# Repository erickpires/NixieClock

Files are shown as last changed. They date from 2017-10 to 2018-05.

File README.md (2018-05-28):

# The Project

This is a clock that uses Nixie Tubes as display. The idea is not new and there are hundreds of others Nixie based clock on the internet.
I got inspired to build the clock after watching a video from [Techmoan](https://www.youtube.com/channel/UC5I2hjZYiW9gZPVkvzM8_Cw).

## The Nixies

The Nixie Tubes were bought from eBay. They are IN-14 tubes desoldered from unused replacement board for old equipment (so the seller told me).

To drive the Nixies, six K155ID1 (the Russian version of the 74141) were also bought from eBay (which turned out to be a bad idea since those chips are very old, not reliable and consume too much power).

The Nixies are powered with 170V and half of their nominal amperage (this should extend their lifetime).

## The Boards

The clock is divided in three boards: a High-Voltage Power Supply for the Nixie Tubes, a Logic Board and a board to hold the Nixies.

* The Power Supply was built on a prototyping PCB based on two designs found online. More information can be found on the Power Supply directory of this repository.

* The Logic Board contains an Atmel Atmega 328p microcontroller which implements the clock in software. This board also contains some passive components and connectors. The schematic and the PCB design was done using kicad and can be found under the kicad/LowerBoard directory. The board itself was homemade using the toner transfer technique (more information can be found online) and etched using ferric chloride.

* The third board holds the Nixie Tubes as well as the six driver ICs and three 74HC573 8-bit transparent latches. This board also functions as the upper face of the clock and the ICs were put in this board because I thought it would be more aesthetically pleasing. The PCB design can be found under the kicad/Clock directory. This board was made using the same technique as the Logic Board.

## The Code

The code runs on an Atmega 328p with an Arduino bootloader. The code doesn't use any of the Arduino library functions, accessing registers directly. The code should work fine without the Arduino environment and using the Atmel Studio. The Arduino environment is used only to provide a n easy way of uploading the code into the microcontroller.

The clock is implemented in software, as already mentioned. The code also handles debouncing of the input buttons and rotary encoder.

Every whole minute the clock plays an animation in which all digits of all Nixie Tubes are lit twice. The primary reason for the animation is to avoid [Cathode Poisoning](http://www.tube-tester.com/sites/nixie/different/cathode%20poisoning/cathode-poisoning.htm) since must of the digits don't change too often (and some digits aren't even lit) but also because it looks cool.

From midnight to 6AM the display is shutdown. This should save some lifetime out of the Nixies. Upon interaction with any button (or rotary encoder) while the display is off, it turns on for 5 seconds.

An alarm clock functionality is planned, but not yet implemented.

## Final Result

Here are two photos of the clock working.

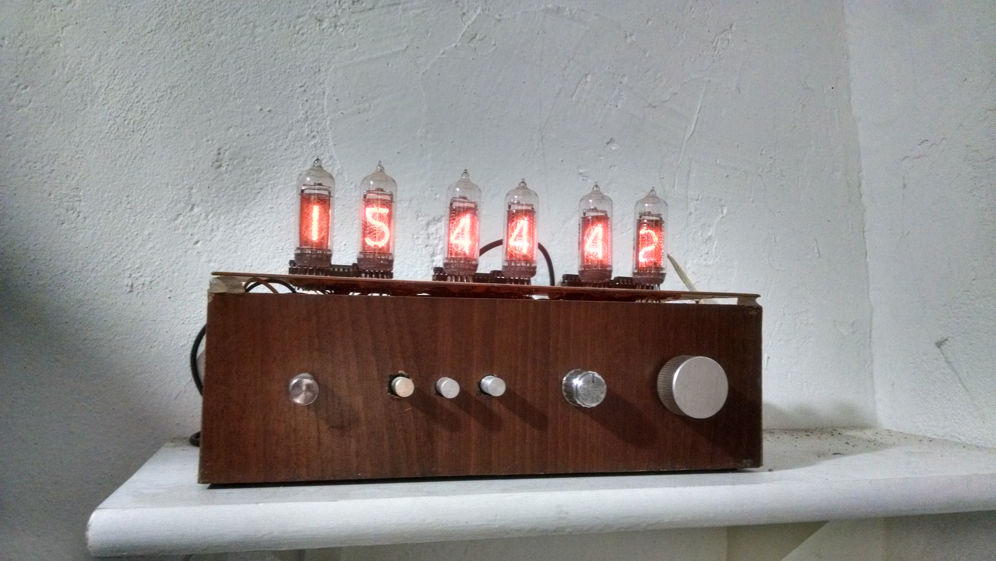
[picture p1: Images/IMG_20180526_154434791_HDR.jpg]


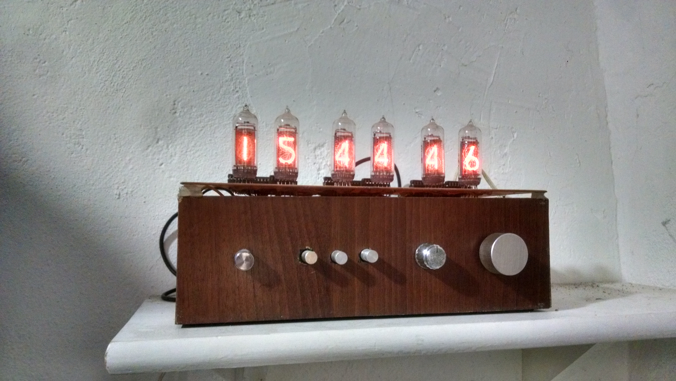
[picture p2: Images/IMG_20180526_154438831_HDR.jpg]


and a video:

Video (https://youtu.be/pQ4-Zf7qyXU)

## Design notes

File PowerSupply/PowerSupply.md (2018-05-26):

# Power Supply

The Power Supply is based in this two designs:

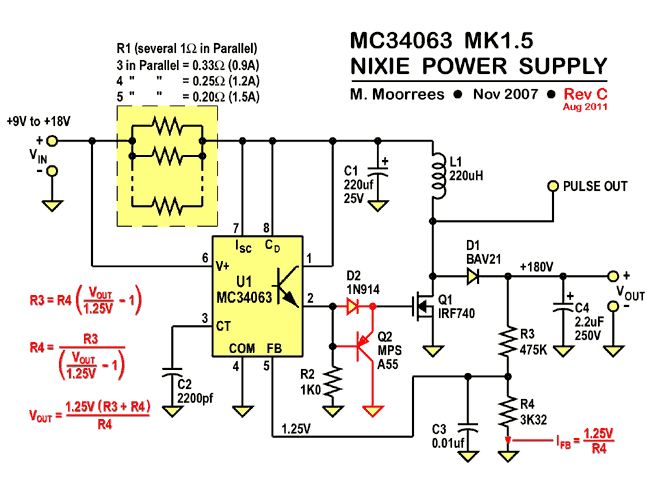
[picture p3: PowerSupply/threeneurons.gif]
ThreeNeurons


and

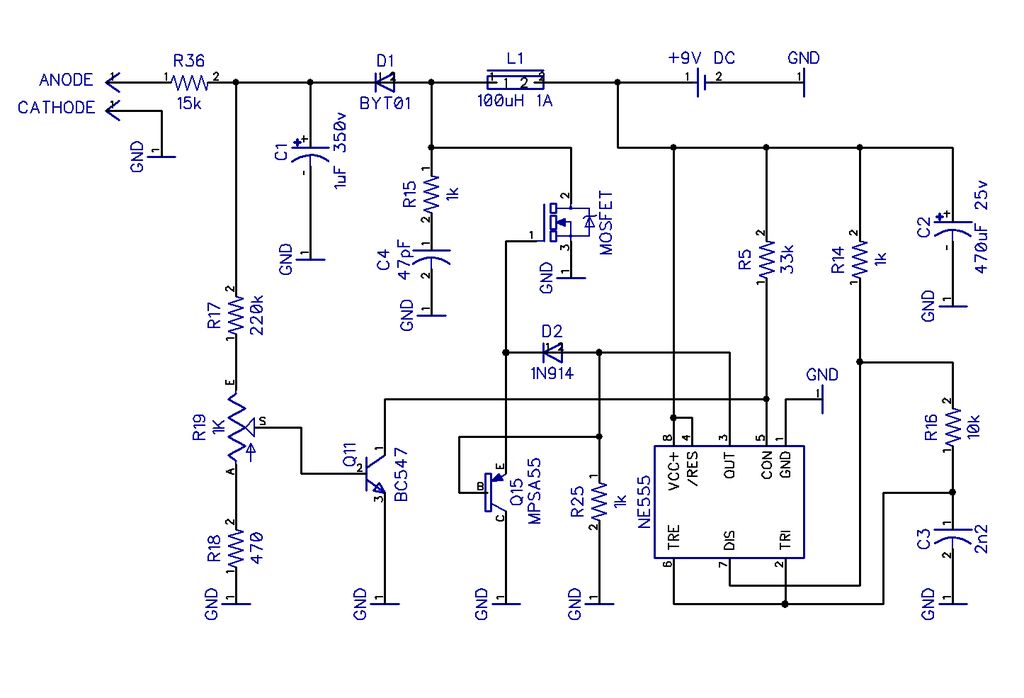
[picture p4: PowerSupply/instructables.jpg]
Instructables


Found in theses two links: [threeneurons](https://threeneurons.wordpress.com/nixie-power-supply/) and [Instructables](http://www.instructables.com/id/High-Voltage-Power-Supply-for-Nixie-and-Valve-Tube/)

Unfortunately I don't have a schematic from the actual Power Supply.

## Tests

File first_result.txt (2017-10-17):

First correction
23:15:31 -> 0:57:0

10:07:01 -> 11:48:00
39090 segundos -> 39060

Second correction : first attempt
10:25:33(~32) -> 0:1:0
Failed miserably

Second correction : second attempt
22:52:24 -> 0:1:0

13:49:21 -> 14:58:0
53817 segundos -> 53820

Third correction
14:04:38 -> 0:1:0

10:12:39 -> 20:9:0
72481 segundos -> 72480

Fourth correction
15:42:50 -> 0:6:0

10:51:58 -> 19:14:0

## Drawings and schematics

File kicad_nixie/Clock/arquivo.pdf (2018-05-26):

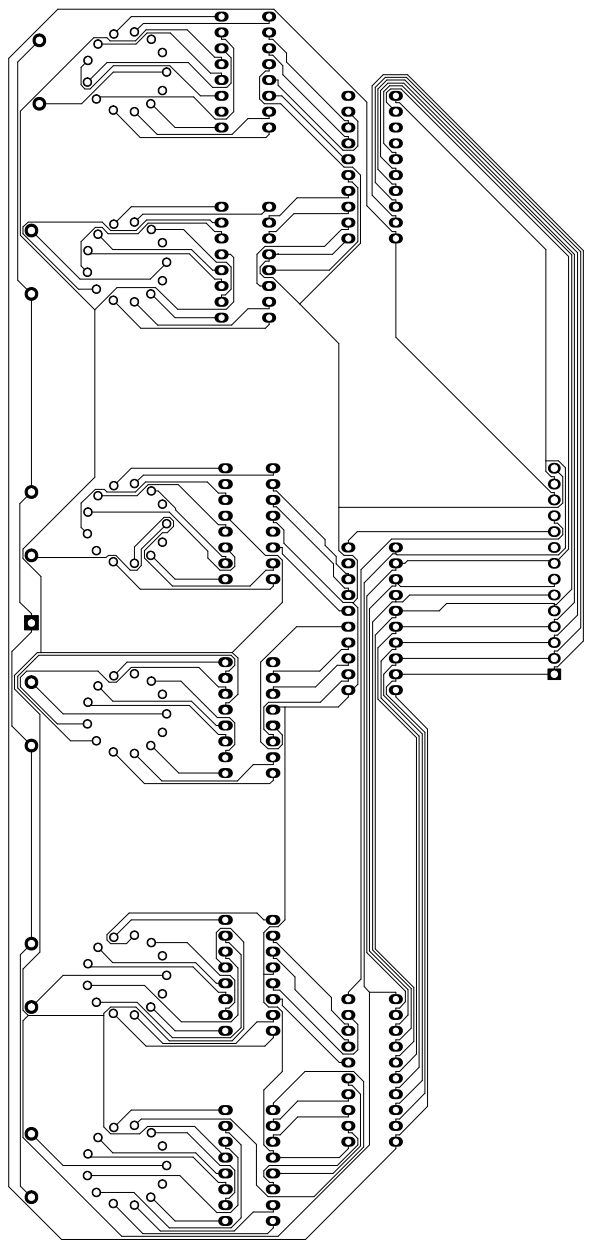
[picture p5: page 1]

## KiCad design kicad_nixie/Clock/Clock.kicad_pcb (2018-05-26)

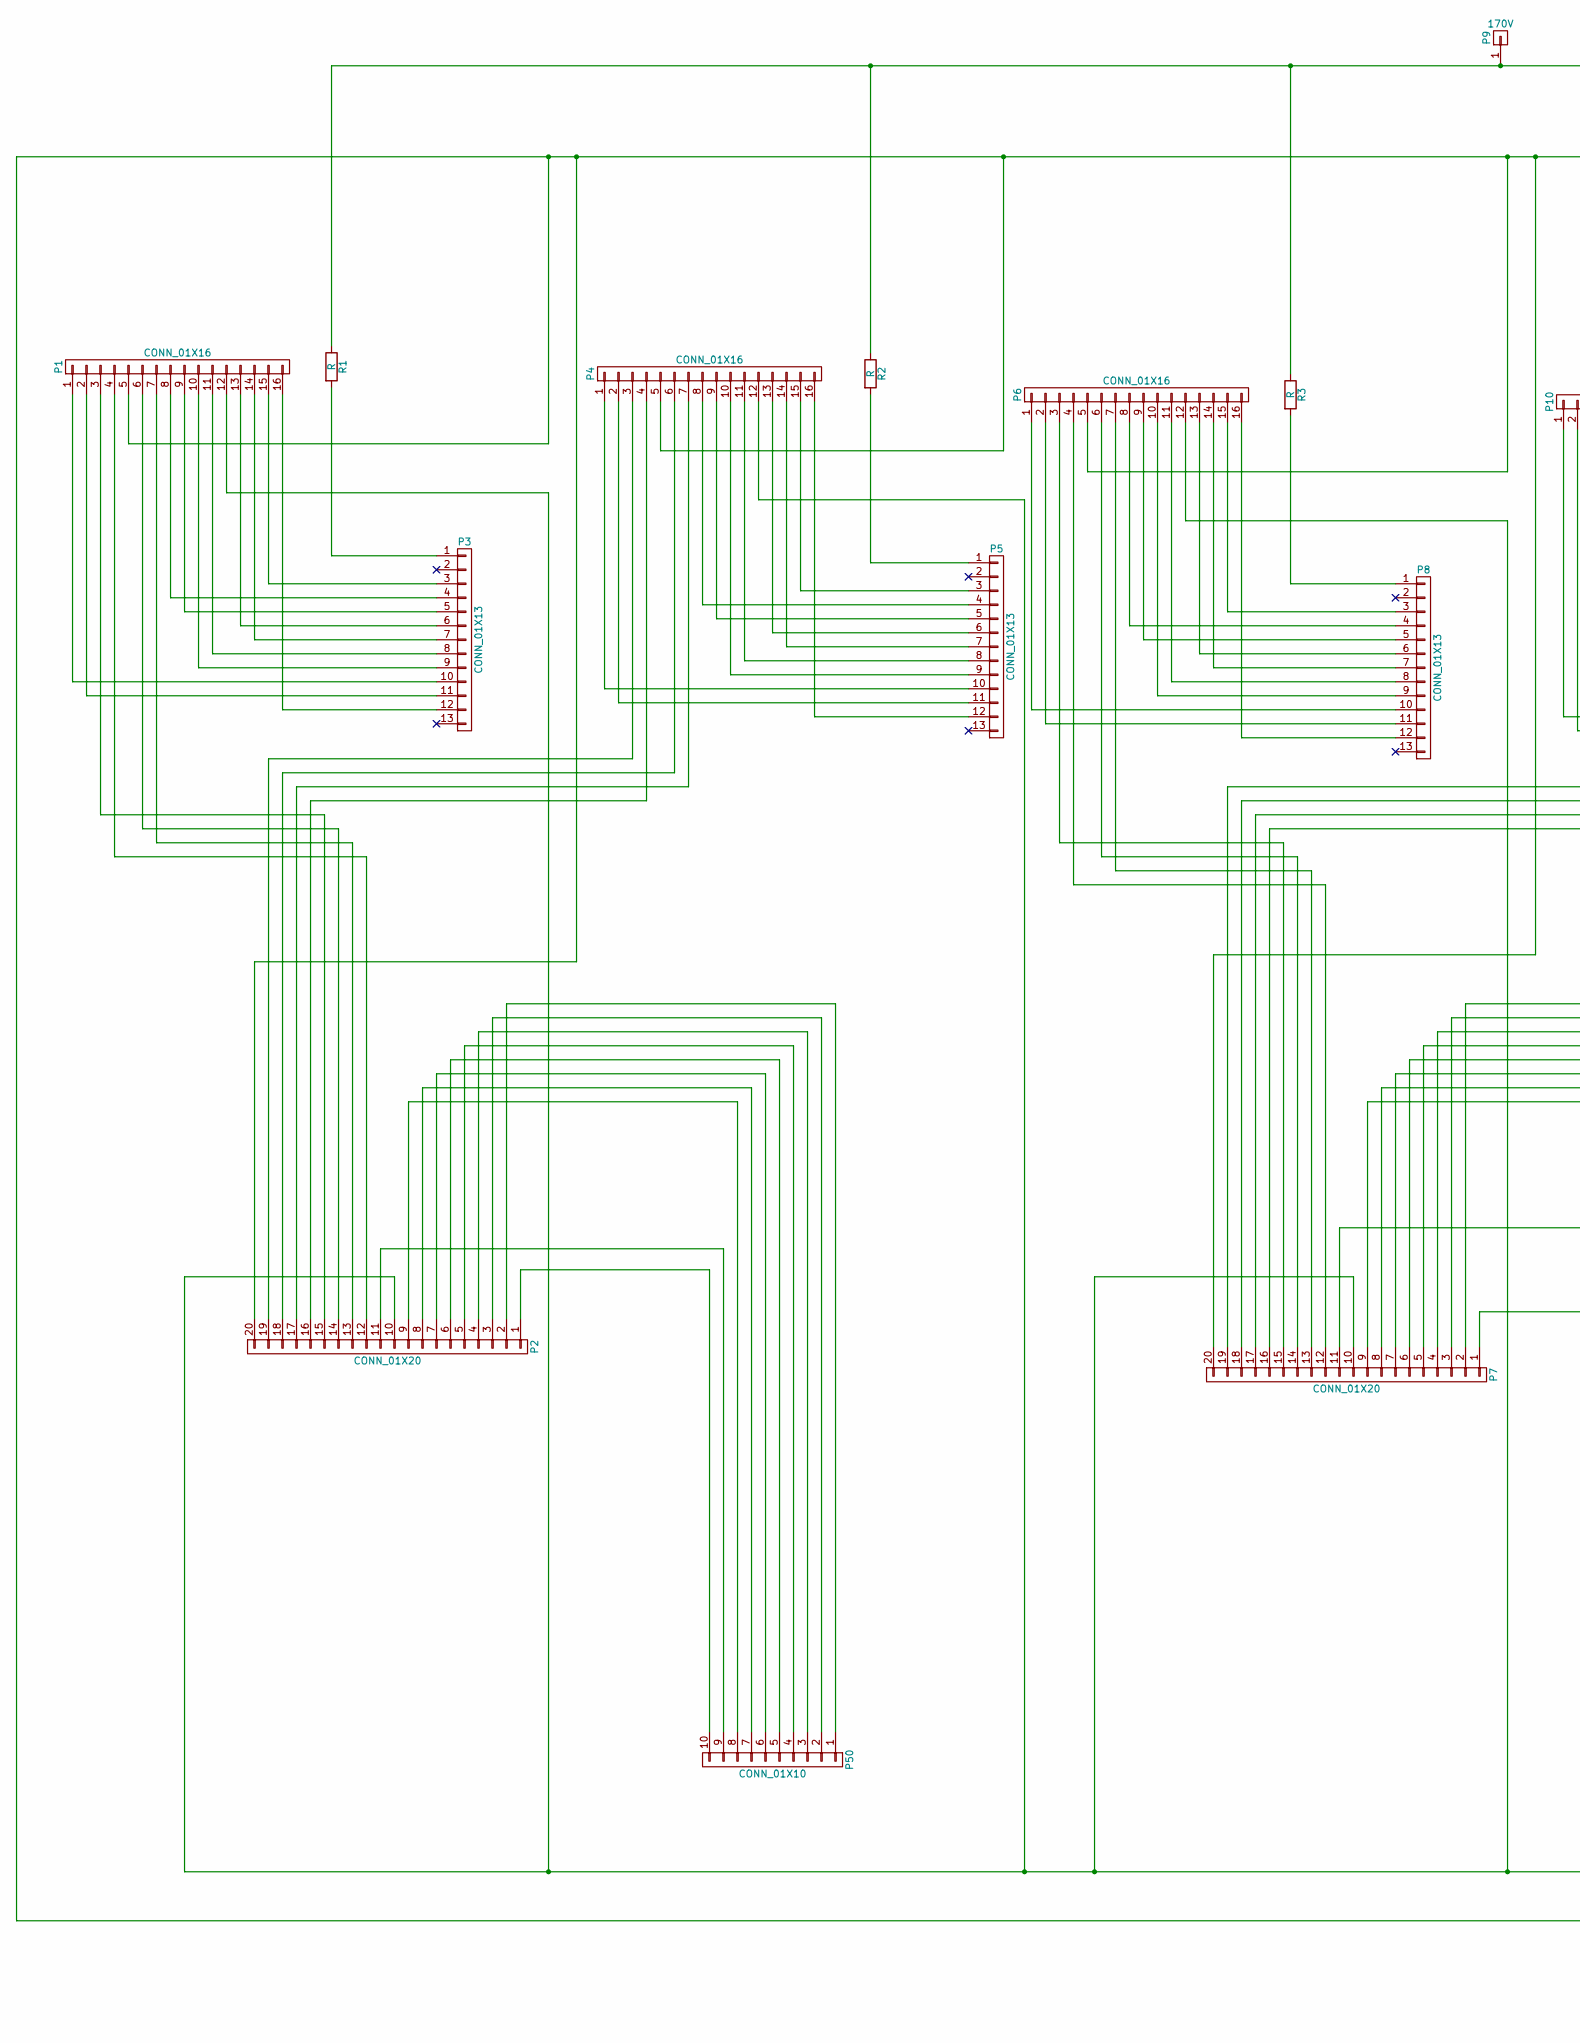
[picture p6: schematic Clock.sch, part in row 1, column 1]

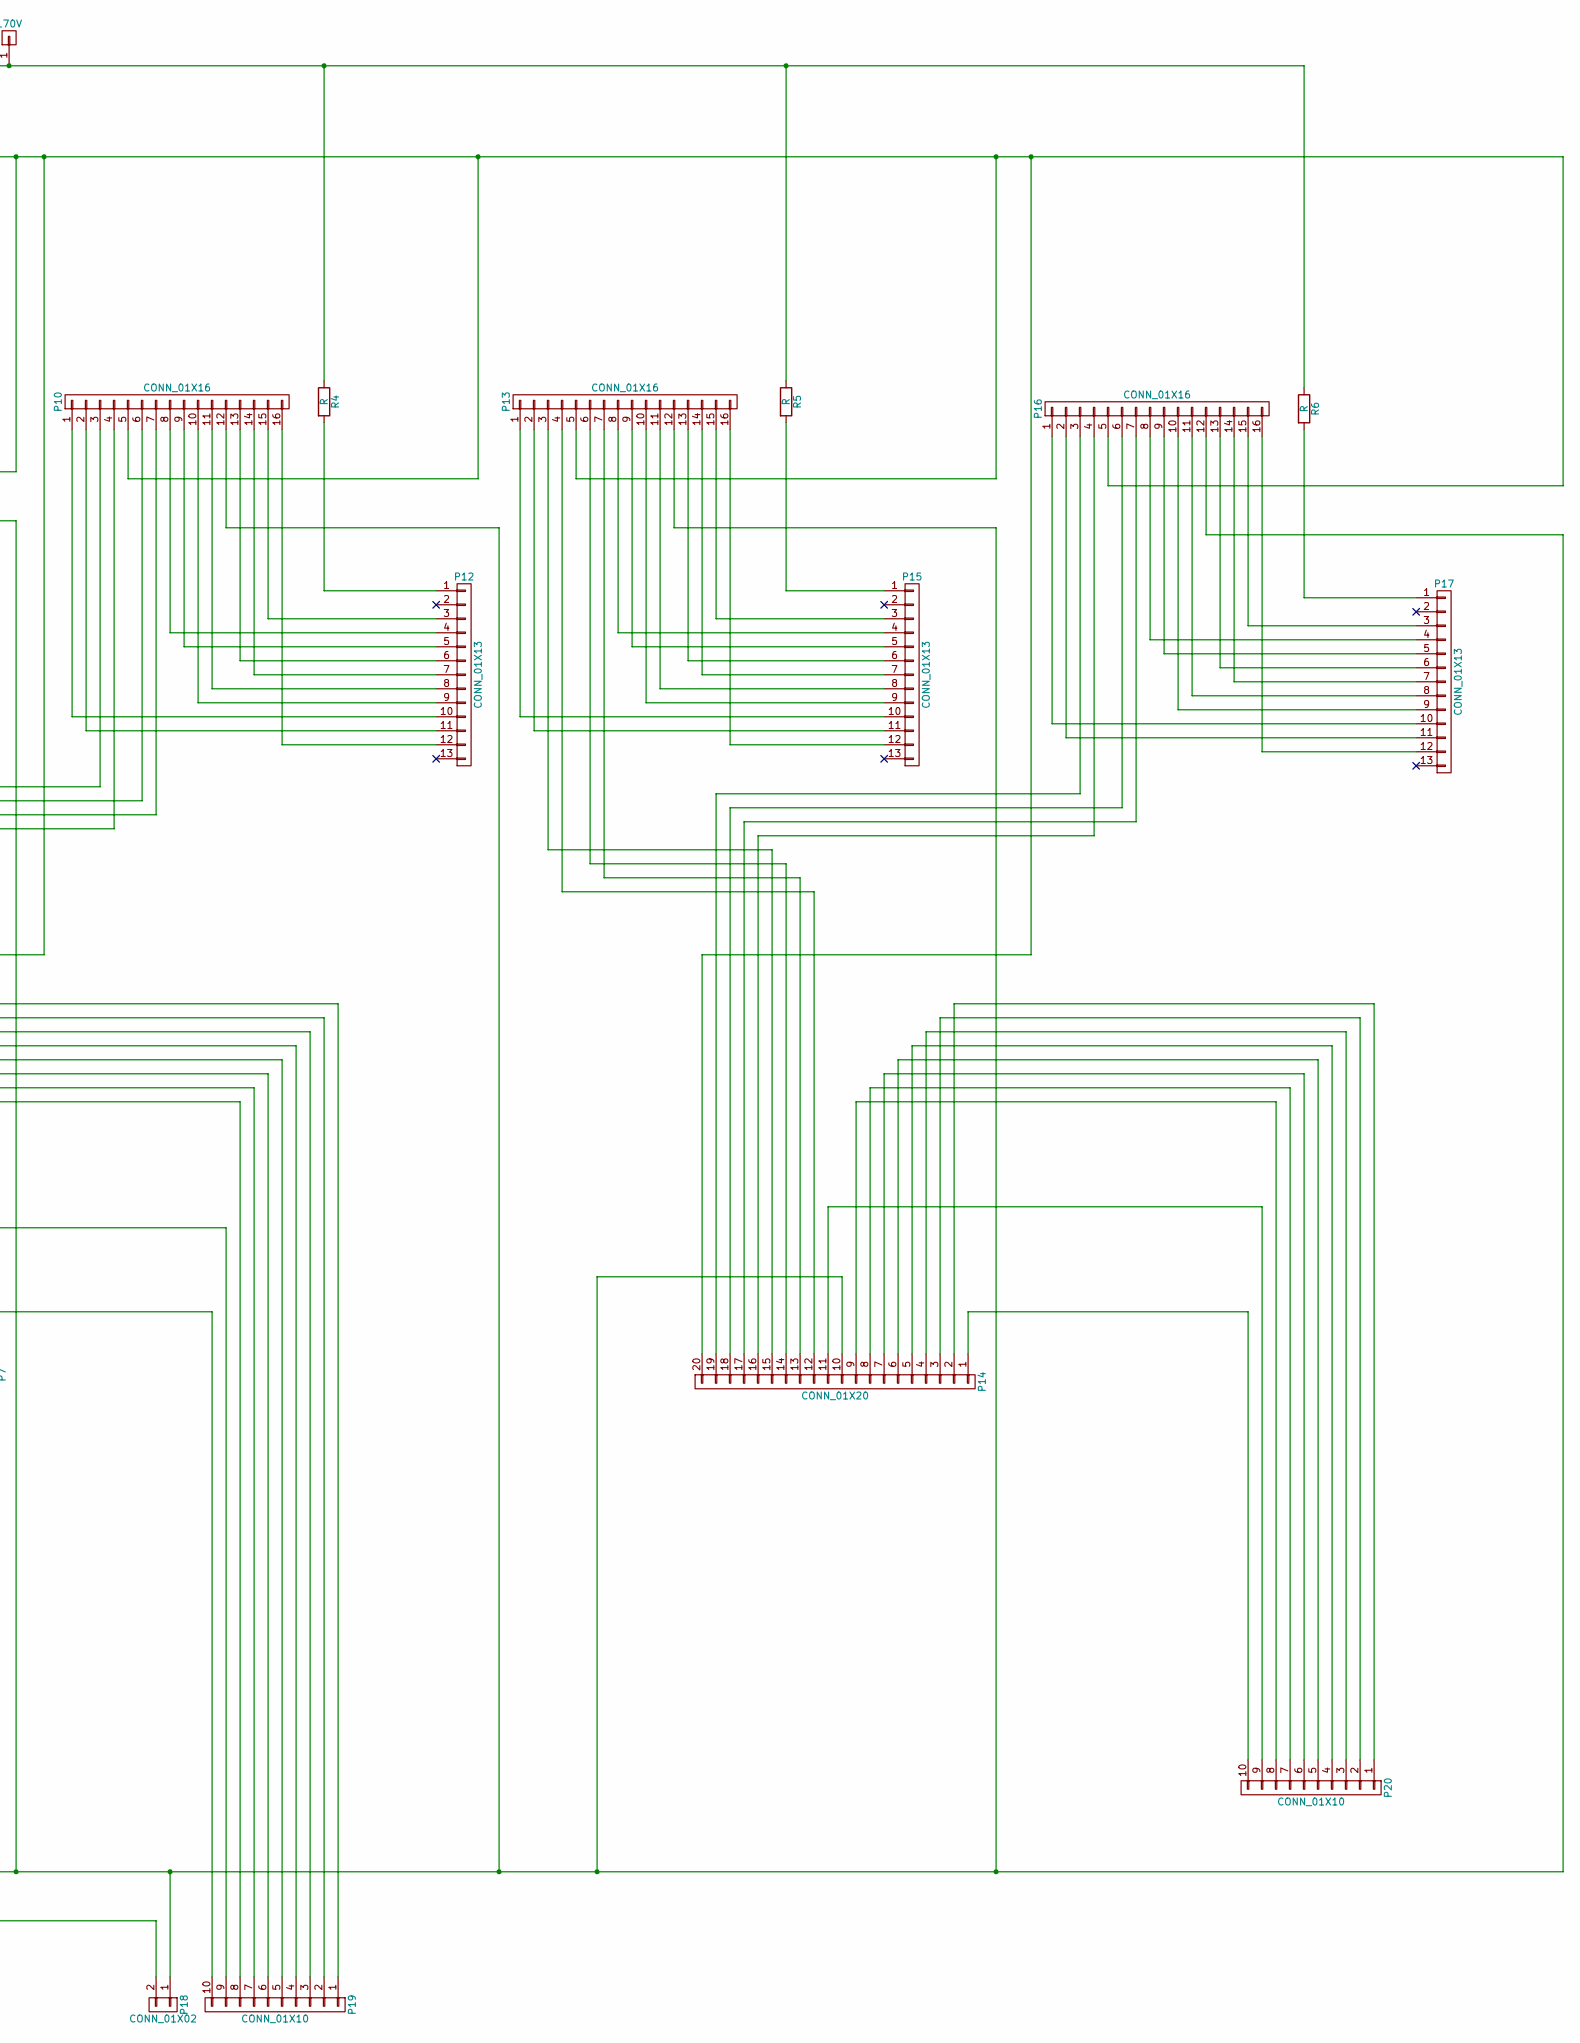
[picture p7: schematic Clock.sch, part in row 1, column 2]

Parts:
P1, P4, P6, P10, P13, P16: CONN_01X16; DIP-16_W7.62mm_LongPads
P2, P7, P14: CONN_01X20; DIP-20_W7.62mm_LongPads
P3, P5, P8, P12, P15, P17: CONN_01X13; IN-14-mod
P9: 170V; Pin_Header_Straight_1x01
P18: CONN_01X02; Pin_Header_Straight_1x02
P19, P20, P50: CONN_01X10; Pin_Header_Straight_1x10
R1, R2, R3, R4, R5, R6: R; Resistor_Horizontal_RM10mm

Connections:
unnamed: P1.1, P3.10
unnamed: P1.2, P3.11
unnamed: P1.3, P2.15
unnamed: P1.4, P2.12
unnamed: P1.5, P2.20, P4.5, P6.5, P7.20, P10.5, P13.5, P14.20, P16.5, P18.2
unnamed: P1.6, P2.14
unnamed: P1.7, P2.13
unnamed: P1.8, P3.4
unnamed: P1.9, P3.5
unnamed: P1.10, P3.9
unnamed: P1.11, P3.8
unnamed: P1.12, P2.10, P4.12, P6.12, P7.10, P10.12, P13.12, P14.10, P16.12, P18.1
unnamed: P1.13, P3.6
unnamed: P1.14, P3.7
unnamed: P1.15, P3.3
unnamed: P1.16, P3.12
unnamed: P2.1, P50.10
unnamed: P2.2, P50.1
unnamed: P2.3, P50.2
unnamed: P2.4, P50.3
unnamed: P2.5, P50.4
unnamed: P2.6, P50.5
unnamed: P2.7, P50.6
unnamed: P2.8, P50.7
unnamed: P2.9, P50.8
unnamed: P2.11, P50.9
unnamed: P2.16, P4.4
unnamed: P2.17, P4.7
unnamed: P2.18, P4.6
unnamed: P2.19, P4.3
unnamed: P3.1, R1.2
unnamed: P4.1, P5.10
unnamed: P4.2, P5.11
unnamed: P4.8, P5.4
unnamed: P4.9, P5.5
unnamed: P4.10, P5.9
unnamed: P4.11, P5.8
unnamed: P4.13, P5.6
unnamed: P4.14, P5.7
unnamed: P4.15, P5.3
unnamed: P4.16, P5.12
unnamed: P5.1, R2.2
unnamed: P6.1, P8.10
unnamed: P6.2, P8.11
unnamed: P6.3, P7.15
unnamed: P6.4, P7.12
unnamed: P6.6, P7.14
unnamed: P6.7, P7.13
unnamed: P6.8, P8.4
unnamed: P6.9, P8.5
unnamed: P6.10, P8.9
unnamed: P6.11, P8.8
unnamed: P6.13, P8.6
unnamed: P6.14, P8.7
unnamed: P6.15, P8.3
unnamed: P6.16, P8.12
unnamed: P8.1, R3.2
unnamed: P9.1, R1.1, R2.1, R3.1, R4.1, R5.1, R6.1
unnamed: P10.1, P12.10
unnamed: P10.2, P12.11
unnamed: P7.19, P10.3
unnamed: P7.16, P10.4
unnamed: P7.18, P10.6
unnamed: P7.17, P10.7
unnamed: P10.8, P12.4
unnamed: P10.9, P12.5
unnamed: P10.10, P12.9
unnamed: P10.11, P12.8
unnamed: P10.13, P12.6
unnamed: P10.14, P12.7
unnamed: P10.15, P12.3
unnamed: P10.16, P12.12
unnamed: P12.1, R4.2
unnamed: P13.1, P15.10
unnamed: P13.2, P15.11
unnamed: P13.3, P14.15
unnamed: P13.4, P14.12
unnamed: P13.6, P14.14
unnamed: P13.7, P14.13
unnamed: P13.8, P15.4
unnamed: P13.9, P15.5
unnamed: P13.10, P15.9
unnamed: P13.11, P15.8
unnamed: P13.13, P15.6
unnamed: P13.14, P15.7
unnamed: P13.15, P15.3
unnamed: P13.16, P15.12
unnamed: P14.1, P20.10
unnamed: P14.2, P20.1
unnamed: P14.3, P20.2
unnamed: P14.4, P20.3
unnamed: P14.5, P20.4
unnamed: P14.6, P20.5
unnamed: P14.7, P20.6
unnamed: P14.8, P20.7
unnamed: P14.9, P20.8
unnamed: P14.11, P20.9
unnamed: P14.16, P16.4
unnamed: P14.17, P16.7
unnamed: P14.18, P16.6
unnamed: P14.19, P16.3
unnamed: P15.1, R5.2
unnamed: P16.1, P17.10
unnamed: P16.2, P17.11
unnamed: P16.8, P17.4
unnamed: P16.9, P17.5
unnamed: P16.10, P17.9
unnamed: P16.11, P17.8
unnamed: P16.13, P17.6
unnamed: P16.14, P17.7
unnamed: P16.15, P17.3
unnamed: P16.16, P17.12
unnamed: P17.1, R6.2
unnamed: P7.2, P19.1
unnamed: P7.3, P19.2
unnamed: P7.4, P19.3
unnamed: P7.5, P19.4
unnamed: P7.6, P19.5
unnamed: P7.7, P19.6
unnamed: P7.8, P19.7
unnamed: P7.9, P19.8
unnamed: P7.11, P19.9
unnamed: P7.1, P19.10

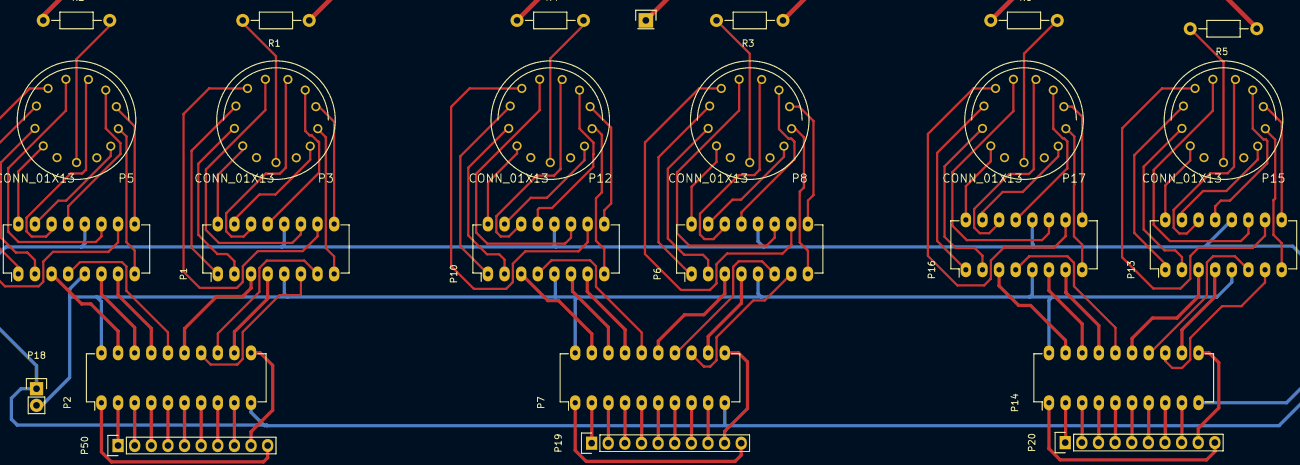
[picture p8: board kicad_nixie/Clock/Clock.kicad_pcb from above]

Board: 2 copper layers, 26 parts (0 on the bottom side), 123 nets.

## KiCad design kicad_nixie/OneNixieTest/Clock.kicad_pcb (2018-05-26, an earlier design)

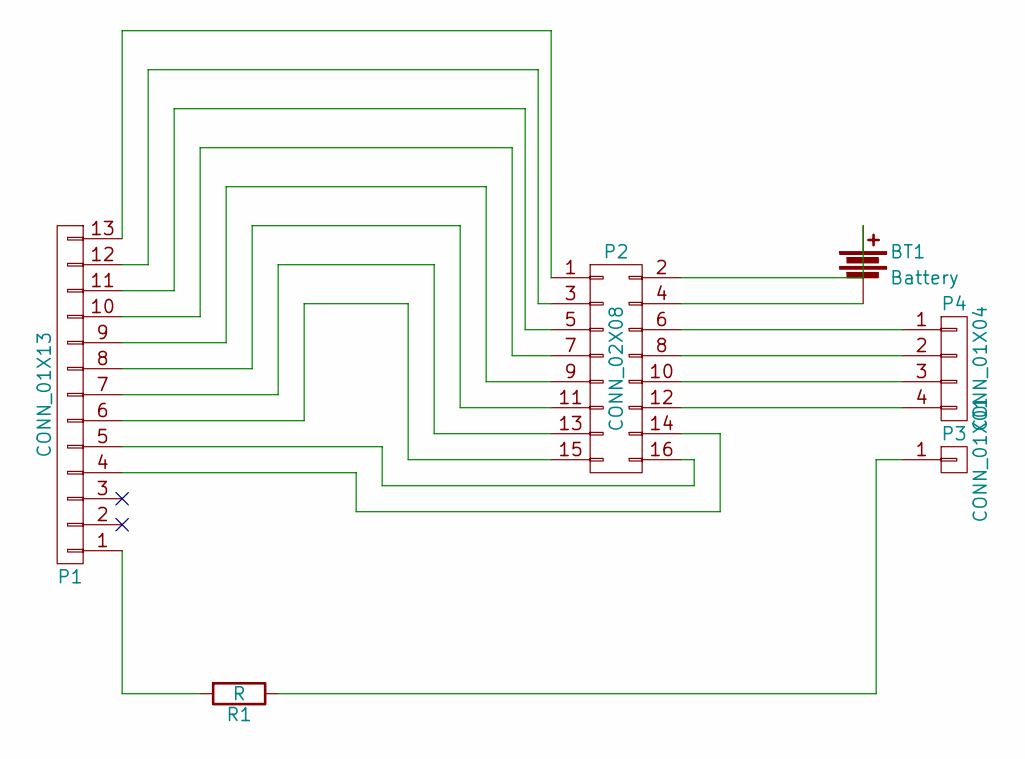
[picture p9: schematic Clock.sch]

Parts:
BT1: Battery; Pin_Header_Straight_1x02
P1: CONN_01X13; IN-14-mod
P2: CONN_02X08; DIP-16_W7.62mm_LongPads
P3: CONN_01X01; Pin_Header_Straight_1x01
P4: CONN_01X04; Pin_Header_Straight_1x04
R1: R; Resistor_Horizontal_RM10mm

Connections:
unnamed: BT1.1, P2.2
unnamed: BT1.2, P2.4
unnamed: P1.1, R1.2
unnamed: P1.4, P2.14
unnamed: P1.5, P2.16
unnamed: P1.6, P2.15
unnamed: P1.7, P2.13
unnamed: P1.8, P2.11
unnamed: P1.9, P2.9
unnamed: P1.10, P2.7
unnamed: P1.11, P2.5
unnamed: P1.12, P2.3
unnamed: P1.13, P2.1
unnamed: P2.6, P4.1
unnamed: P2.8, P4.2
unnamed: P2.10, P4.3
unnamed: P2.12, P4.4
unnamed: P3.1, R1.1

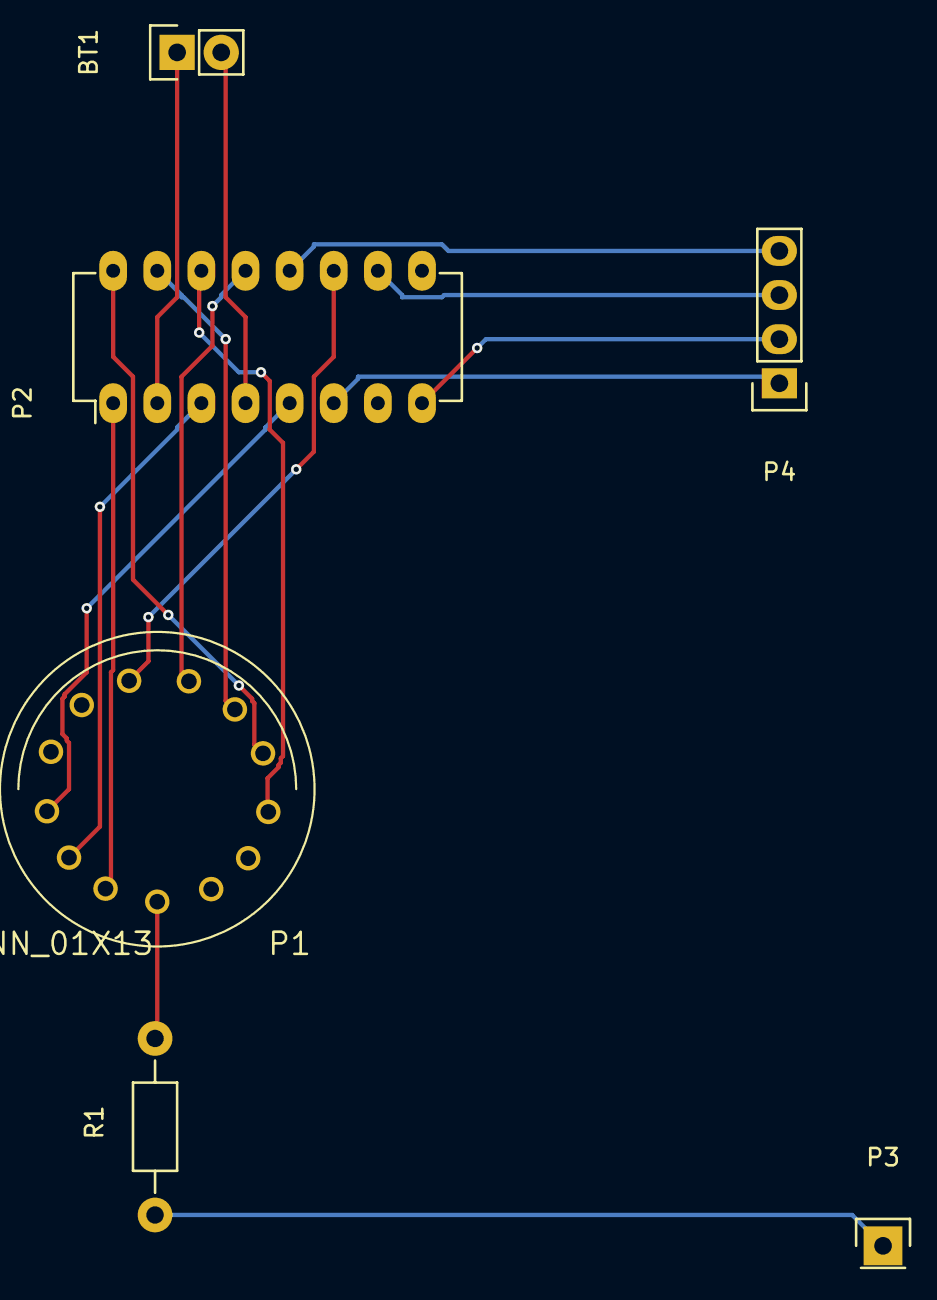
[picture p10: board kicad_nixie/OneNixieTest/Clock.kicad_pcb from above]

Board: 2 copper layers, 6 parts (0 on the bottom side), 18 nets.

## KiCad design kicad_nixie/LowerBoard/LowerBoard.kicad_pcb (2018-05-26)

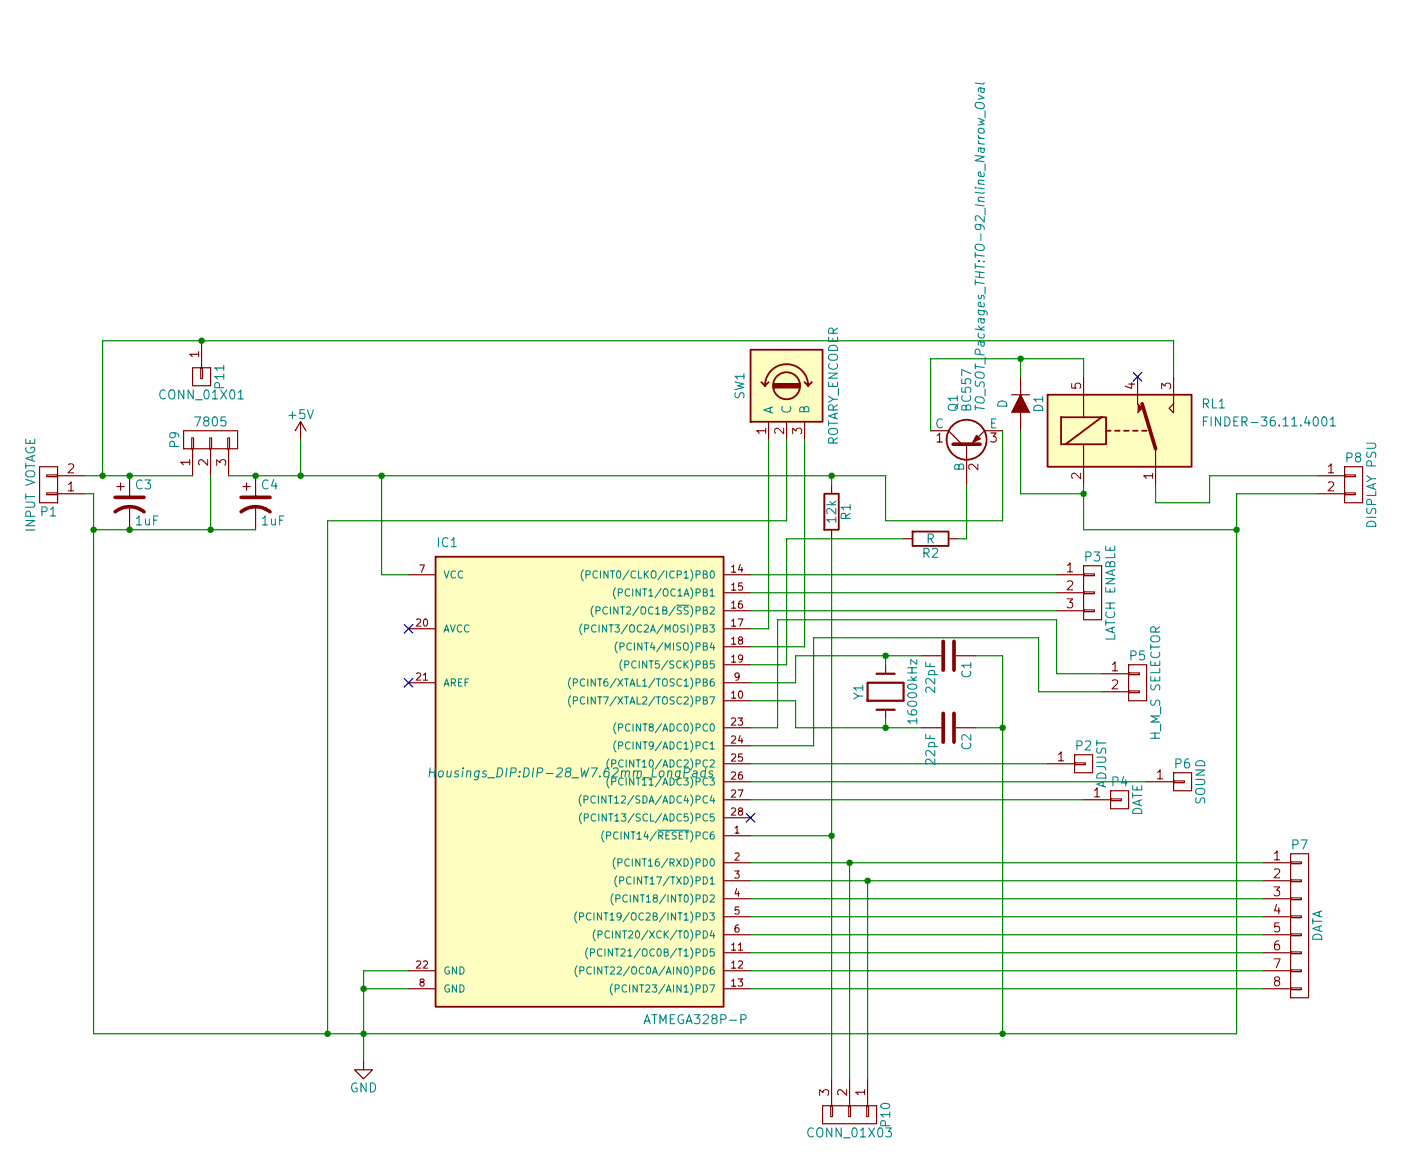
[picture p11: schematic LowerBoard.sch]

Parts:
C1, C2: 22pF; C_Disc_D3_P2.5
C3, C4: 1uF; C_Radial_D5_L11_P2.5
D1: D; Diode_DO-35_SOD27_Horizontal_RM10
IC1: ATMEGA328P-P; DIP-28_W7.62mm_LongPads
P1: INPUT VOTAGE; Pin_Header_Straight_1x02
P2: ADJUST; Pin_Header_Straight_1x01
P3: LATCH ENABLE; Pin_Header_Straight_1x03
P4: DATE; Pin_Header_Straight_1x01
P5: H_M_S SELECTOR; Pin_Header_Straight_1x02
P6: SOUND; Pin_Header_Straight_1x01
P7: DATA; Pin_Header_Straight_1x08
P8: DISPLAY PSU; Pin_Header_Straight_1x02
P9: 7805; TO-220
P10: CONN_01X03; Pin_Header_Straight_1x03
P11: CONN_01X01; Pin_Header_Straight_1x01
Q1: BC557; TO-92_Inline_Narrow_Oval
R1: 12k; Resistor_Horizontal_RM7mm
R2: R; Resistor_Horizontal_RM7mm
RL1: FINDER-36.11.4001; Relay_SANYOU_SRD_Series_Form_C
SW1: ROTARY_ENCODER; Pin_Header_Straight_1x03
Y1: 16000kHz; Crystal_HC50-U_Vertical

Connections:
+5V: C4.1, IC1.7 (VCC), P9.3, Q1.3 (E), R1.1
GND: C1.1, C2.1, C3.2, C4.2, D1.2 (A), IC1.8 (GND), IC1.22 (GND), P1.1, P8.2, P9.2, RL1.2, SW1.2 (C)
unnamed: C1.2, IC1.9 ((PCINT6/XTAL1/TOSC1)PB6), Y1.2
unnamed: C2.2, IC1.10 ((PCINT7/XTAL2/TOSC2)PB7), Y1.1
unnamed: C3.1, P1.2, P9.1, P11.1, RL1.3
unnamed: D1.1 (K), Q1.1 (C), RL1.5
unnamed: IC1.1 ((PCINT14/~RESET~)PC6), P10.3, R1.2
unnamed: IC1.2 ((PCINT16/RXD)PD0), P7.1, P10.2
unnamed: IC1.3 ((PCINT17/TXD)PD1), P7.2, P10.1
unnamed: IC1.4 ((PCINT18/INT0)PD2), P7.3
unnamed: IC1.5 ((PCINT19/OC2B/INT1)PD3), P7.4
unnamed: IC1.6 ((PCINT20/XCK/T0)PD4), P7.5
unnamed: IC1.11 ((PCINT21/OC0B/T1)PD5), P7.6
unnamed: IC1.12 ((PCINT22/OC0A/AIN0)PD6), P7.7
unnamed: IC1.13 ((PCINT23/AIN1)PD7), P7.8
unnamed: IC1.14 ((PCINT0/CLKO/ICP1)PB0), P3.1
unnamed: IC1.15 ((PCINT1/OC1A)PB1), P3.2
unnamed: IC1.16 ((PCINT2/OC1B/~SS~)PB2), P3.3
unnamed: IC1.17 ((PCINT3/OC2A/MOSI)PB3), SW1.1 (A)
unnamed: IC1.18 ((PCINT4/MISO)PB4), SW1.3 (B)
unnamed: IC1.19 ((PCINT5/SCK)PB5), R2.2
unnamed: IC1.23 ((PCINT8/ADC0)PC0), P5.1
unnamed: IC1.24 ((PCINT9/ADC1)PC1), P5.2
unnamed: IC1.25 ((PCINT10/ADC2)PC2), P2.1
unnamed: IC1.26 ((PCINT11/ADC3)PC3), P6.1
unnamed: IC1.27 ((PCINT12/SDA/ADC4)PC4), P4.1
unnamed: P8.1, RL1.1
unnamed: Q1.2 (B), R2.1

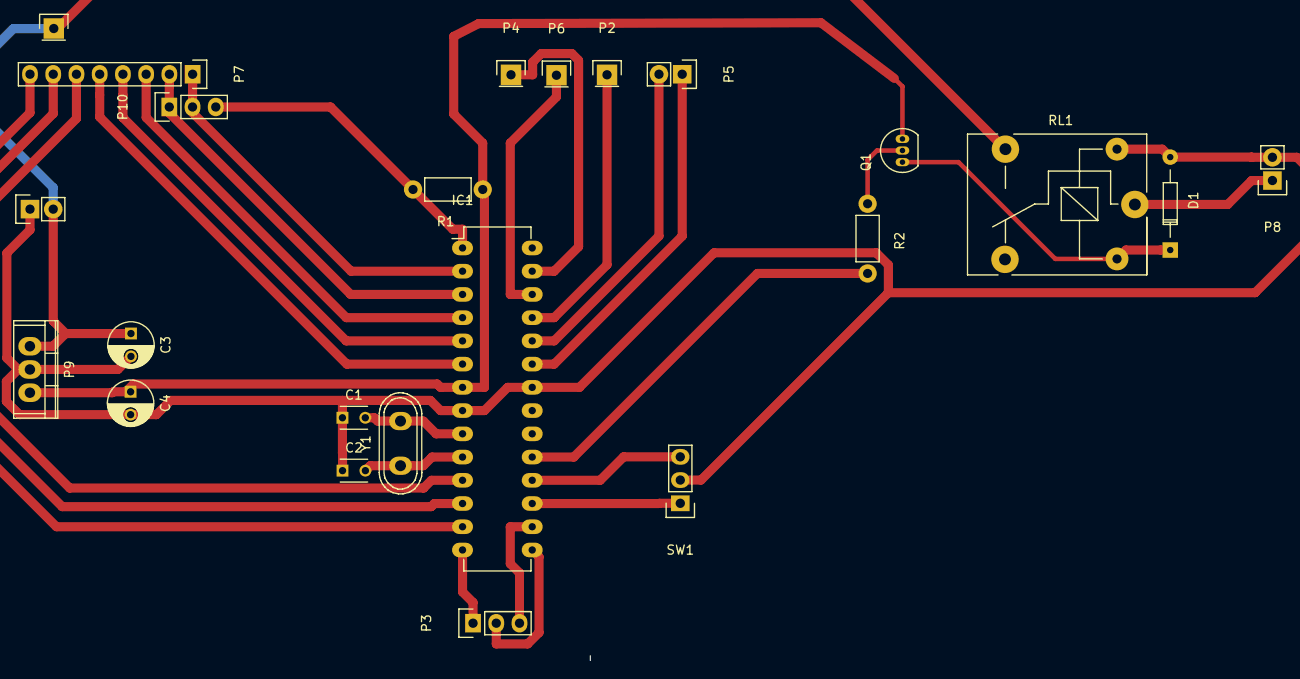
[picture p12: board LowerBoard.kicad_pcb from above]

Board: 2 copper layers, 23 parts (0 on the bottom side), 28 nets.

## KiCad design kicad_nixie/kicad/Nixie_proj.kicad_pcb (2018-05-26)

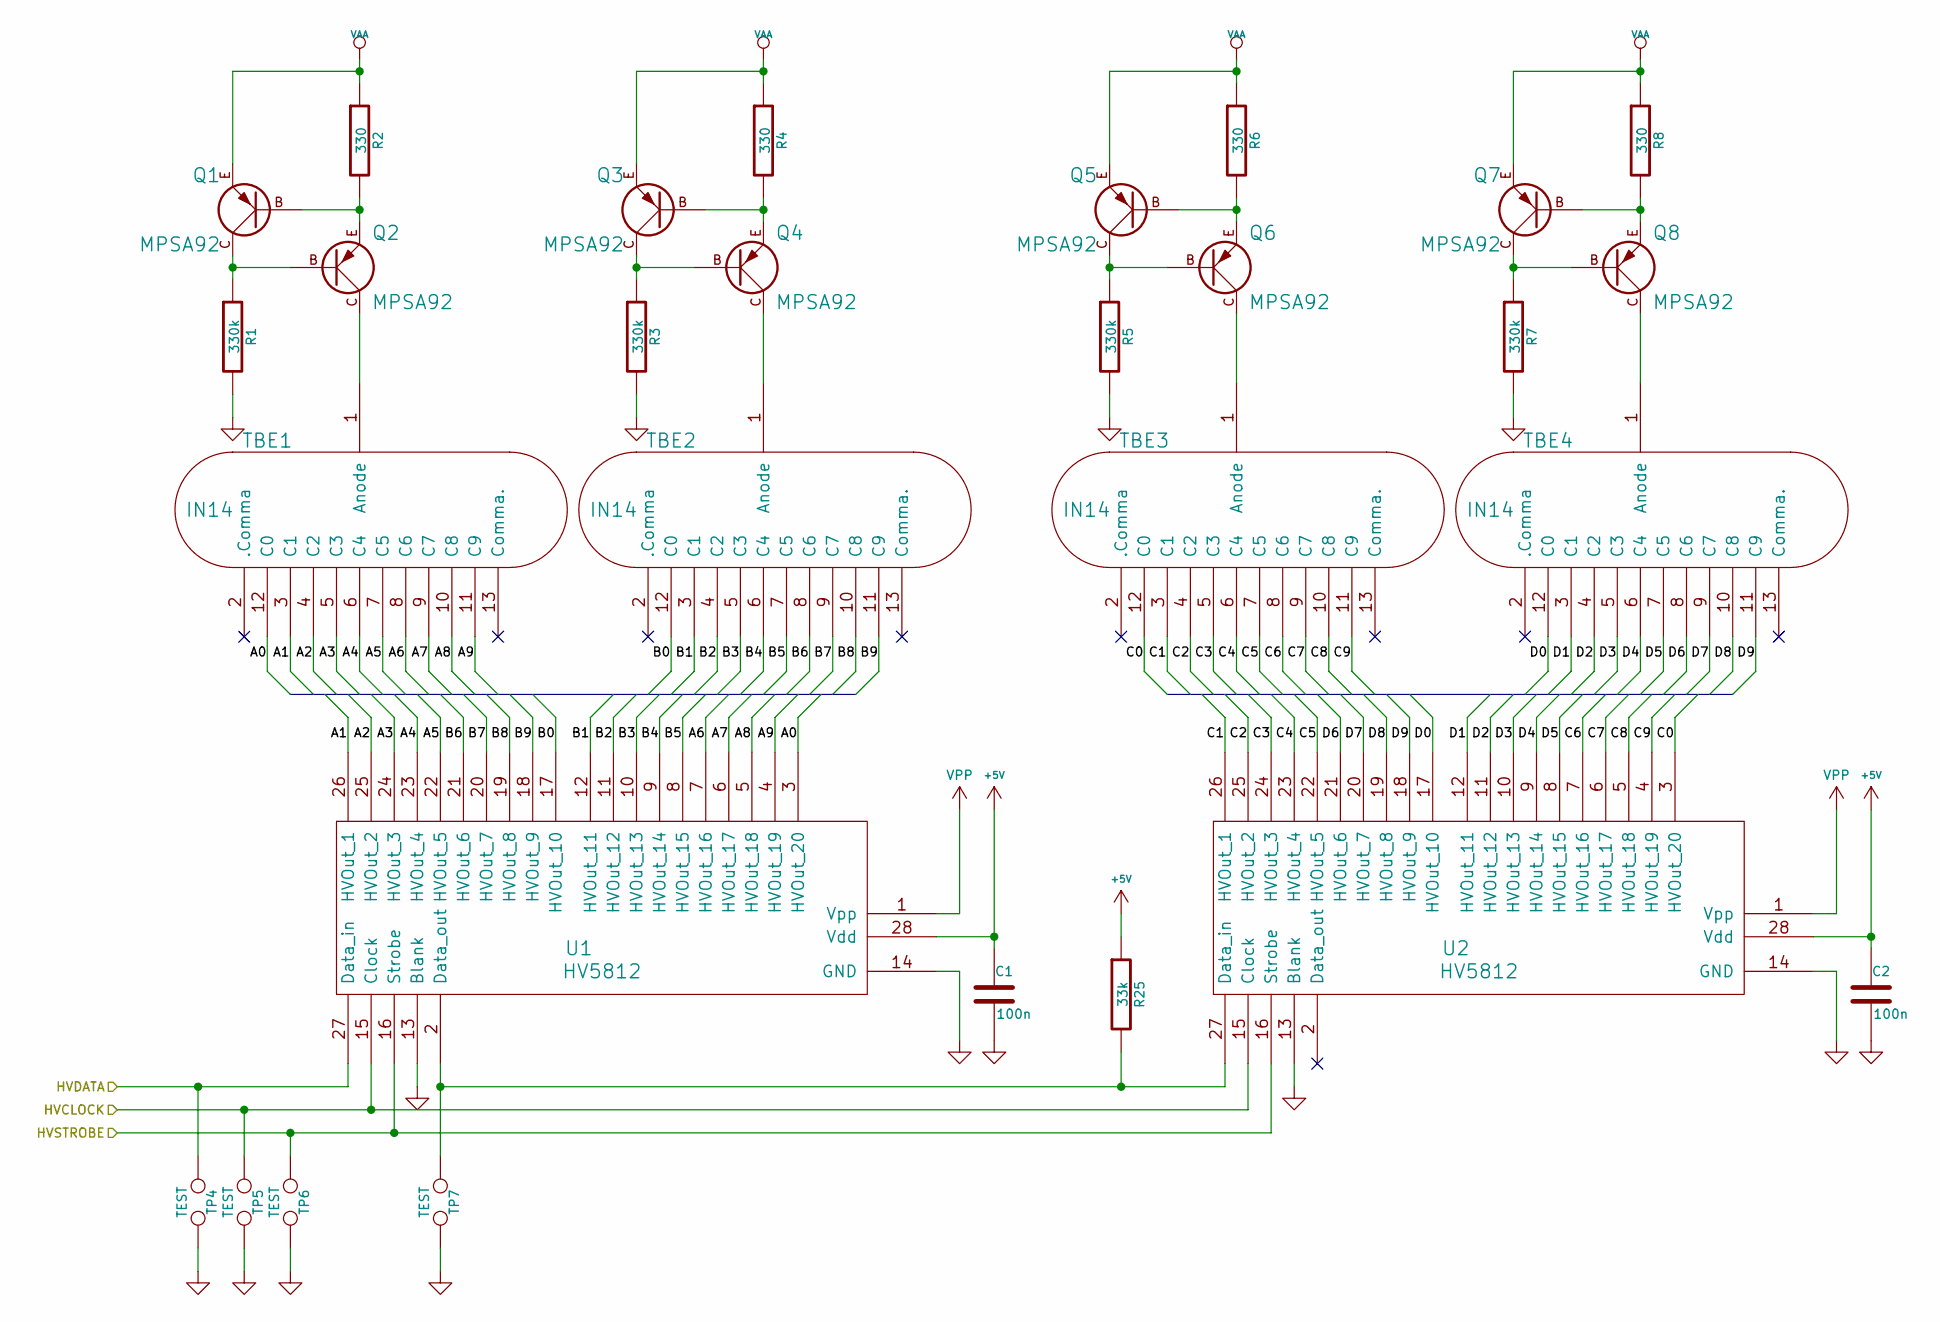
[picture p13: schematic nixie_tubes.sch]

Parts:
C1, C2: 100n; c_0805
Q1, Q2, Q3, Q4, Q5, Q6, Q7, Q8: MPSA92; TO92-CBE
R1, R3, R5, R7: 330k; R3-mod
R2, R4, R6, R8: 330; R3-mod
R25: 33k; R0805_smd-mod
TBE1, TBE2, TBE3, TBE4: IN14; IN-14-mod
TP4, TP5, TP6, TP7: TEST; GS2
U1, U2: HV5812; SO28W-mod

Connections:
+5V: C1.1, C2.1, R25.1, U1.28 (Vdd), U2.28 (Vdd); also elsewhere on the board
/Microcontroller and clock/HVCLOCK: TP5.1, U1.15 (Clock), U2.15 (Clock); also elsewhere on the board
/Microcontroller and clock/HVDATA: TP4.1, U1.27 (Data_in); also elsewhere on the board
/Microcontroller and clock/HVSTROBE: TP6.1, U1.16 (Strobe), U2.16 (Strobe); also elsewhere on the board
/Tubes with drivers/A0: TBE1.12 (C0), U1.3 (HVOut_20)
/Tubes with drivers/A1: TBE1.3 (C1), U1.26 (HVOut_1)
/Tubes with drivers/A2: TBE1.4 (C2), U1.25 (HVOut_2)
/Tubes with drivers/A3: TBE1.5 (C3), U1.24 (HVOut_3)
/Tubes with drivers/A4: TBE1.6 (C4), U1.23 (HVOut_4)
/Tubes with drivers/A5: TBE1.7 (C5), U1.22 (HVOut_5)
/Tubes with drivers/A6: TBE1.8 (C6), U1.7 (HVOut_16)
/Tubes with drivers/A7: TBE1.9 (C7), U1.6 (HVOut_17)
/Tubes with drivers/A8: TBE1.10 (C8), U1.5 (HVOut_18)
/Tubes with drivers/A9: TBE1.11 (C9), U1.4 (HVOut_19)
/Tubes with drivers/B0: TBE2.12 (C0), U1.17 (HVOut_10)
/Tubes with drivers/B1: TBE2.3 (C1), U1.12 (HVOut_11)
/Tubes with drivers/B2: TBE2.4 (C2), U1.11 (HVOut_12)
/Tubes with drivers/B3: TBE2.5 (C3), U1.10 (HVOut_13)
/Tubes with drivers/B4: TBE2.6 (C4), U1.9 (HVOut_14)
/Tubes with drivers/B5: TBE2.7 (C5), U1.8 (HVOut_15)
/Tubes with drivers/B6: TBE2.8 (C6), U1.21 (HVOut_6)
/Tubes with drivers/B7: TBE2.9 (C7), U1.20 (HVOut_7)
/Tubes with drivers/B8: TBE2.10 (C8), U1.19 (HVOut_8)
/Tubes with drivers/B9: TBE2.11 (C9), U1.18 (HVOut_9)
/Tubes with drivers/C0: TBE3.12 (C0), U2.3 (HVOut_20)
/Tubes with drivers/C1: TBE3.3 (C1), U2.26 (HVOut_1)
/Tubes with drivers/C2: TBE3.4 (C2), U2.25 (HVOut_2)
/Tubes with drivers/C3: TBE3.5 (C3), U2.24 (HVOut_3)
/Tubes with drivers/C4: TBE3.6 (C4), U2.23 (HVOut_4)
/Tubes with drivers/C5: TBE3.7 (C5), U2.22 (HVOut_5)
/Tubes with drivers/C6: TBE3.8 (C6), U2.7 (HVOut_16)
/Tubes with drivers/C7: TBE3.9 (C7), U2.6 (HVOut_17)
/Tubes with drivers/C8: TBE3.10 (C8), U2.5 (HVOut_18)
/Tubes with drivers/C9: TBE3.11 (C9), U2.4 (HVOut_19)
/Tubes with drivers/D0: TBE4.12 (C0), U2.17 (HVOut_10)
/Tubes with drivers/D1: TBE4.3 (C1), U2.12 (HVOut_11)
/Tubes with drivers/D2: TBE4.4 (C2), U2.11 (HVOut_12)
/Tubes with drivers/D3: TBE4.5 (C3), U2.10 (HVOut_13)
/Tubes with drivers/D4: TBE4.6 (C4), U2.9 (HVOut_14)
/Tubes with drivers/D5: TBE4.7 (C5), U2.8 (HVOut_15)
/Tubes with drivers/D6: TBE4.8 (C6), U2.21 (HVOut_6)
/Tubes with drivers/D7: TBE4.9 (C7), U2.20 (HVOut_7)
/Tubes with drivers/D8: TBE4.10 (C8), U2.19 (HVOut_8)
/Tubes with drivers/D9: TBE4.11 (C9), U2.18 (HVOut_9)
GND: C1.2, C2.2, R1.2, R3.2, R5.2, R7.2, TP4.2, TP5.2, TP6.2, TP7.2, U1.13 (Blank), U1.14 (GND), U2.13 (Blank), U2.14 (GND); also elsewhere on the board
unnamed: Q1.B, Q2.E, R2.2
unnamed: Q1.C, Q2.B, R1.1
unnamed: Q2.C, TBE1.1 (Anode)
unnamed: Q3.B, Q4.E, R4.2
unnamed: Q3.C, Q4.B, R3.1
unnamed: Q4.C, TBE2.1 (Anode)
unnamed: Q5.B, Q6.E, R6.2
unnamed: Q5.C, Q6.B, R5.1
unnamed: Q6.C, TBE3.1 (Anode)
unnamed: Q7.B, Q8.E, R8.2
unnamed: Q7.C, Q8.B, R7.1
unnamed: Q8.C, TBE4.1 (Anode)
unnamed: R25.2, TP7.1, U1.2 (Data_out), U2.27 (Data_in)
VAA: Q1.E, Q3.E, Q5.E, Q7.E, R2.1, R4.1, R6.1, R8.1; also elsewhere on the board
VPP: U1.1 (Vpp), U2.1 (Vpp); also elsewhere on the board

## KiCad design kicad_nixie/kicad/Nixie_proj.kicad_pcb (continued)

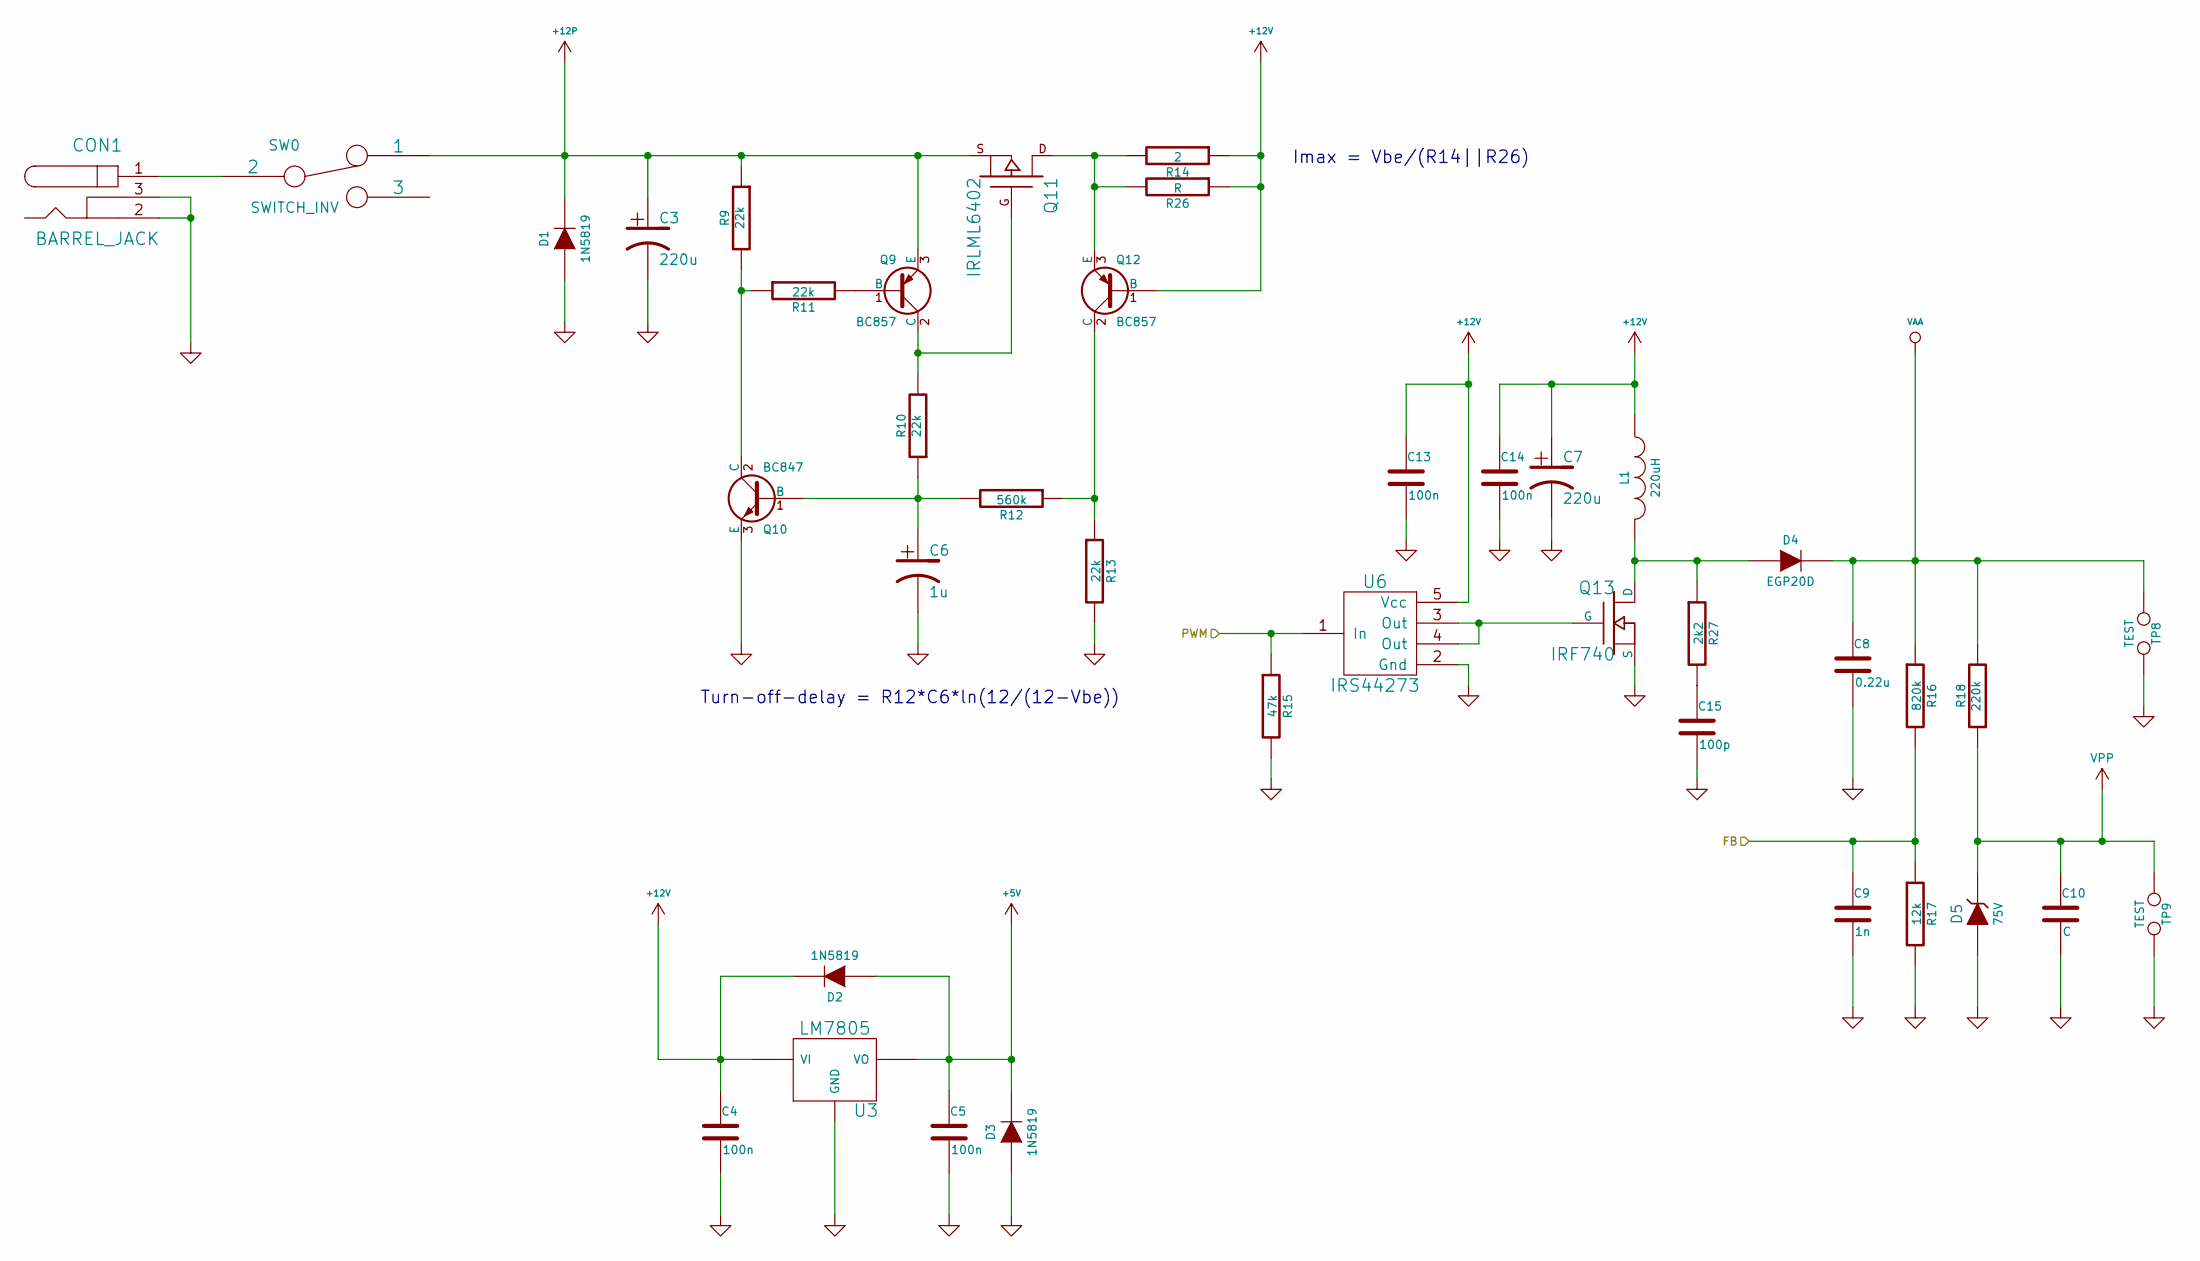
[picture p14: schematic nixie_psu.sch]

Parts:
C3, C7: 220u; CP_8x13mm
C4, C5, C13, C14: 100n; c_0805
C6: 1u; CP_5x6mm
C8: 0.22u; C102-054X133
C9: 1n; c_0805
C10: C; c_0805
C15: 100p; c_0805
CON1: BARREL_JACK
D1, D2, D3: 1N5819; D3
D4: EGP20D; D3
D5: 75V; D3
L1: 220uH; INDUCTOR_V
Q9, Q12: BC857; sot23
Q10: BC847; sot23
Q11: IRLML6402; SOT23GDS
Q13: IRF740; TO220GDS_VERT
R9, R10, R11, R13: 22k; R0805_smd-mod
R12: 560k; R0805_smd-mod
R14: 2; R3-mod
R15: 47k; R0805_smd-mod
R16: 820k; R3-mod
R17: 12k; R3-mod
R18: 220k; R3-mod
R26: R; R3-mod
R27: 2k2; R3-mod
SW0: SWITCH_INV; CL-SA-12C4-02
TP8, TP9: TEST; GS2
U3: LM7805; TO-220
U6: IRS44273; SOT23-5

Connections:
+5V: C5.1, D2.1 (A), D3.2 (K), U3.3 (VO); also elsewhere on the board
+12P: C3.1, D1.2 (K), Q9.3 (E), Q11.S, R9.1, SW0.1
+12V: C4.1, C7.1, C13.1, C14.1, D2.2 (K), L1.1, Q12.1 (B), R14.1, R26.1, U3.1 (VI), U6.5 (Vcc)
/Microcontroller and clock/FB: C9.1, R16.2, R17.1; also elsewhere on the board
/Microcontroller and clock/PWM: R15.1, U6.1 (In); also elsewhere on the board
GND: C3.2, C4.2, C5.2, C6.2, C7.2, C8.2, C9.2, C10.2, C13.2, C14.2, C15.2, CON1.2, CON1.3, D1.1 (A), D3.1 (A), D5.1 (A), Q10.3 (E), Q13.S, R13.2, R15.2, R17.2, TP8.2, TP9.2, U3.2 (GND), U6.2 (Gnd); also elsewhere on the board
unnamed: C6.1, Q10.1 (B), R10.1, R12.2
unnamed: C15.1, R27.2
unnamed: CON1.1, SW0.2
unnamed: D4.1 (A), L1.2, Q13.D, R27.1
unnamed: Q9.1 (B), R11.2
unnamed: Q10.2 (C), R9.2, R11.1
unnamed: Q11.D, Q12.3 (E), R14.2, R26.2
unnamed: Q9.2 (C), Q11.G, R10.2
unnamed: Q12.2 (C), R12.1, R13.1
unnamed: Q13.G, U6.3 (Out), U6.4 (Out)
VAA: C8.1, D4.2 (K), R16.1, R18.2, TP8.1; also elsewhere on the board
VPP: C10.1, D5.2 (K), R18.1, TP9.1; also elsewhere on the board

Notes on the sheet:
Imax = Vbe/(R14||R26)
Turn-off-delay = R12*C6*ln(12/(12-Vbe))

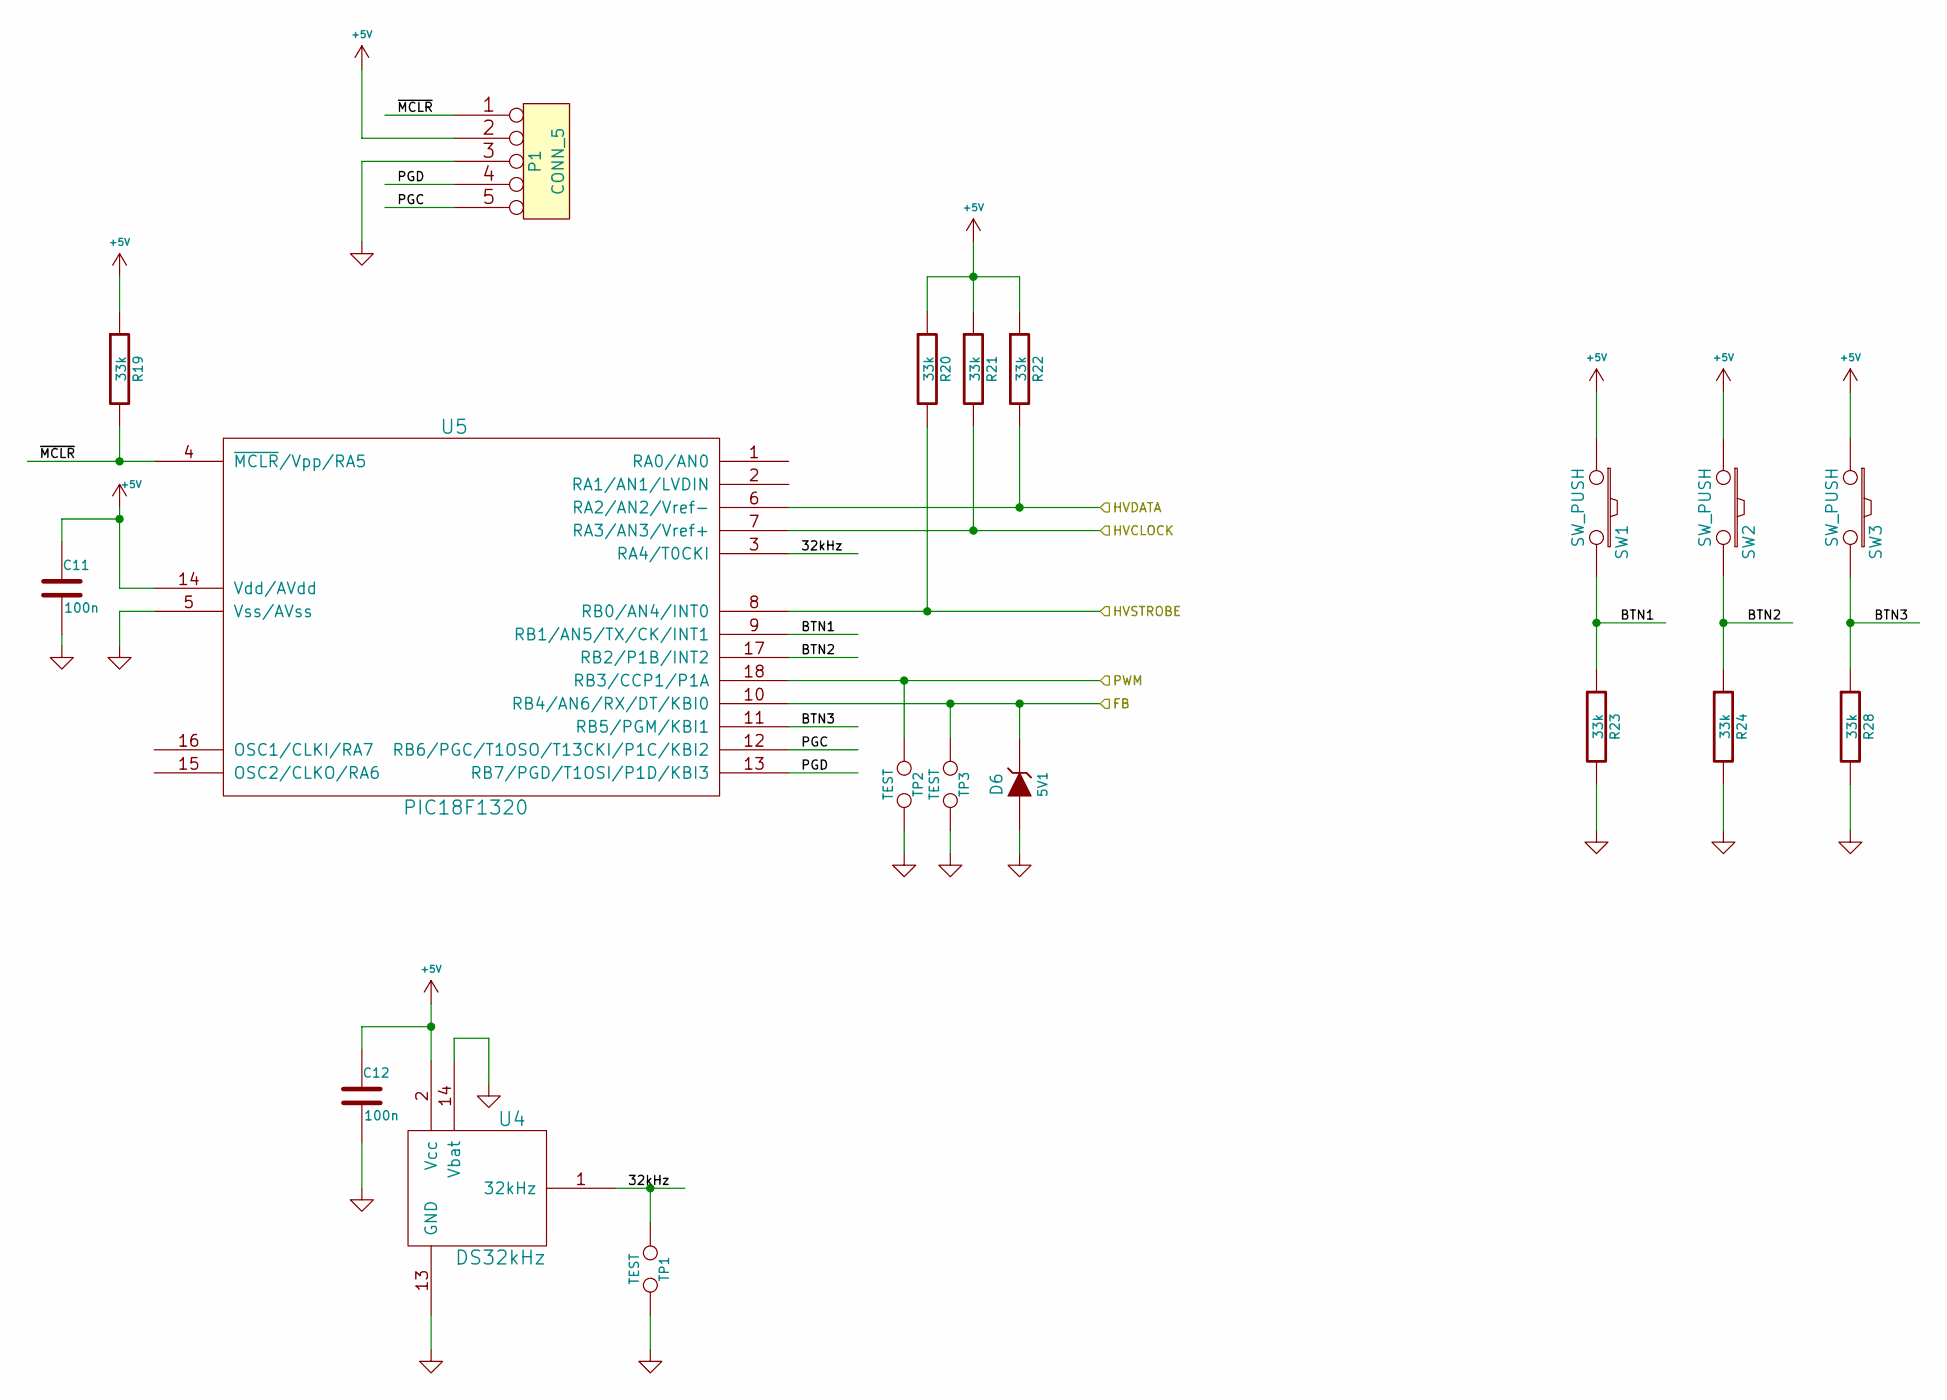
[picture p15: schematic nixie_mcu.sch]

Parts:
C11, C12: 100n; c_0805
D6: 5V1; D3
P1: CONN_5; PIN_ARRAY_5x1
R19, R20, R21, R22, R23, R24, R28: 33k; R0805_smd-mod
SW1, SW2, SW3: SW_PUSH; TL1105L-4,3
TP1, TP2, TP3: TEST; GS2
U4: DS32kHz; SO16W-mod
U5: PIC18F1320; SO18L-mod

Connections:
+5V: C11.1, C12.1, P1.2, R19.1, R20.1, R21.1, R22.1, SW1.1, SW2.1, SW3.1, U4.2 (Vcc), U5.14 (Vdd/AVdd); also elsewhere on the board
/Microcontroller and clock/32kHz: TP1.1, U4.1 (32kHz), U5.3 (RA4/T0CKI)
/Microcontroller and clock/BTN1: R23.1, SW1.2, U5.9 (RB1/AN5/TX/CK/INT1)
/Microcontroller and clock/BTN2: R24.1, SW2.2, U5.17 (RB2/P1B/INT2)
/Microcontroller and clock/BTN3: R28.1, SW3.2, U5.11 (RB5/PGM/KBI1)
/Microcontroller and clock/FB: D6.2 (K), TP3.1, U5.10 (RB4/AN6/RX/DT/KBI0); also elsewhere on the board
/Microcontroller and clock/HVCLOCK: R21.2, U5.7 (RA3/AN3/Vref+); also elsewhere on the board
/Microcontroller and clock/HVDATA: R22.2, U5.6 (RA2/AN2/Vref-); also elsewhere on the board
/Microcontroller and clock/HVSTROBE: R20.2, U5.8 (RB0/AN4/INT0); also elsewhere on the board
/Microcontroller and clock/PGC: P1.5, U5.12 (RB6/PGC/T1OSO/T13CKI/P1C/KBI2)
/Microcontroller and clock/PGD: P1.4, U5.13 (RB7/PGD/T1OSI/P1D/KBI3)
/Microcontroller and clock/PWM: TP2.1, U5.18 (RB3/CCP1/P1A); also elsewhere on the board
/Microcontroller and clock/~MCLR: P1.1, R19.2, U5.4 (~MCLR~/Vpp/RA5)
GND: C11.2, C12.2, D6.1 (A), P1.3, R23.2, R24.2, R28.2, TP1.2, TP2.2, TP3.2, U4.13 (GND), U4.14 (Vbat), U5.5 (Vss/AVss); also elsewhere on the board

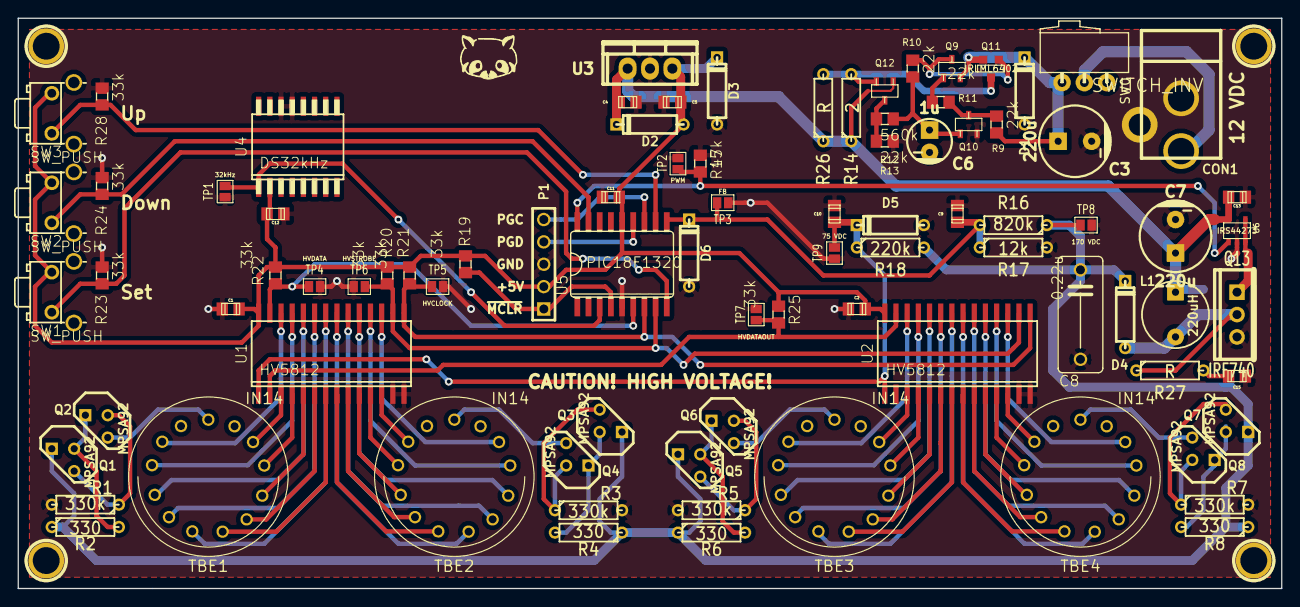
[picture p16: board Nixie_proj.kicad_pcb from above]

Board: 2 copper layers, 143.5 x 64.8 mm, 93 parts (1 on the bottom side), 81 nets.

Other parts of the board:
1PIN, 1PIN#2, 1PIN#3, 1PIN#4: P***; 1pin
Logo_ref: LOGO; Panda_Logo_7x5mm

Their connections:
GND: 1PIN.1, 1PIN#2.1, 1PIN#3.1, 1PIN#4.1; also elsewhere on the board

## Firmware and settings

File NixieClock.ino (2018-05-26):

// Wiring
// PORTD is used as the data bus. The latches data is written to this port.
// PORTB{0-2} are the pins used as latch select. Selection is HIGH.
// PORTB{3,4} are used to decode the information of the Rotary Encoder. The internal pull-up resistors are used.
// PORTB5 is used to switch the display ON and OFF. Active LOW.
// PORTC{0,1} are the pins used for H_M_S selection. The internal pull-up resistors are used. Read below for more information.
// PORTC2 is used to switch between DISPLAY_MODE and ADJUST_MODE. The internal pull-up resistor is used.
// PORTC3 is used to switch the sound ON and OFF. The internal pull-up resistor is used.
// PORTC4 is used to switch between TIME_DISPLAY and DATE_DISPLAY. The internal pull-up resistor is used.
//
// H_M_S Selection

// Inputs
// The inputs are read once every millisecond. Because of the way the inputs of the clock are physically made, very fast
//  reads are unlikely to be needed.
// An software debouncing is implemented using a "count" scheme. 16 samples of the input port are gathered and stored. After the
//  16th sample a variable is set to the value of the last sample and a variable receives a bitfield which tells us the bits that
//  are valid i.e. the bits that did not change across the 16 samples.

// TODO(erick): Move all the constants to the .h file.
#include "NixieClock.h"

// --- Tables ---
const uint8 days_in_mounths[] =
{
    31, 28, 31, 30, 31, 30, 31, 31, 30, 31, 30, 31
};

const static uint8 div10_quot_rem_table[] PROGMEM =
{
    0,    1,    2,   3,   4,   5,   6,   7,   8,   9,
    16,  17,   18,  19,  20,  21,  22,  23,  24,  25,
    32,  33,   34,  35,  36,  37,  38,  39,  40,  41,
    48,  49,   50,  51,  52,  53,  54,  55,  56,  57,
    64,  65,   66,  67,  68,  69,  70,  71,  72,  73,
    80,  81,   82,  83,  84,  85,  86,  87,  88,  89,
    96,  97,   98,  99, 100, 101, 102, 103, 104, 105,
    112, 113, 114, 115, 116, 117, 118, 119, 120, 121,
    128, 129, 130, 131, 132, 133, 134, 135, 136, 137,
    144, 145, 146, 147, 148, 149, 150, 151, 152, 153
};

#define N_INPUT_SAMPLES 16
static uint8 input_array[N_INPUT_SAMPLES];

static uint8 input_valid_bits;
static uint8 input_bitfield;
static uint8 old_input_bitfield;
static uint8 input_array_current_index = 0;
static uint8 new_input_flag = 0;

#define turn_display_on()  PORTB &=  ~(1 << 5)
#define turn_display_off() PORTB |=   (1 << 5)
#define is_display_on() (!(PINB & (1 << 5)))

static volatile uint16 milliseconds = 0;
static volatile uint8 seconds_flag = 0;


static int8 clock_current_second = 0;
static int8 clock_current_minute = 0;
static int8 clock_current_hour = 0;

static int8 clock_current_day = 1;
static int8 clock_current_month = 1;
static int8 clock_current_year = 0;

static uint8 display_mode = DISPLAY_TIME;
static uint8 clock_is_running = 1;

static uint8 display_fade_timeout = 0; // Minutes

// This Rotary Encoder code is base on the code by mathertel
// https://github.com/mathertel/RotaryEncoder
// http://www.mathertel.de/Arduino/RotaryEncoderLibrary.aspx

#define ROTARY_ENCODER_LATCH_STATE 3
static uint8 __rotary_encoder_old_state;
static int8 __rotary_encoder_internal_position;     // Internal position (4 times position)
static int8 __rotary_encoder_old_internal_position;
static int rotary_encoder_position;  // External position


//
// Animation Stuff
//

// NOTE(erick): HOW THE ANIMATION WORKS
//
// The animation scrolls all the digits on all the nixies.
// ANIMATION_LOOPS is the number of scrolls that the animation will have.
// Since the animation scrolls through ten digits, we have `10 * ANIMATION_LOOPS`
// steps in the animation. Every step lasts MILLISECONDS_PER_ANIMATION_STEP milliseconds.
//
// `is_animating` is a boolean variable that indicates whether the clock is aninating
// or not. An animation starts every exact minutes (i.e. when seconds are zero) and
// the clock is not in adjust mode (the `clock_is_running` variable is true). If the
// clock changes to adjust mode and an animation is in progress, the animation is aborted.
//
// `animation_milliseconds` is a helper variable to count modulo MILLISECONDS_PER_ANIMATION_STEP
// without having to do any division (or working modulo some power of two). This variable is
// incremented every millisecond only if `is_animating` is true. Every time reaches zero the
// `animation_counter` is incremented until it reaches ANIMATION_STEPS, then the animation is ended.
//
// Every time the clock has a new animation step it sets the `new_animation_step_flag` so the
// animation can be handled on the main loop.
//
// The animation itself is done by the `update_display` function, that checks whether `is_animating`
// is true and if it is, calculates the value in each digit based on the `animation_counter` variable.

#define ANIMATION_LOOPS 3
#define ANIMATION_STEPS (10 * ANIMATION_LOOPS)
#define MILLISECONDS_PER_ANIMATION_STEP 16
static uint8 is_animating = 0;
static uint8 new_animation_step_flag = 0;
static uint8 animation_counter;
static uint8 animation_milliseconds = 0;

const static uint8 animation_table[] PROGMEM =
{
    34, 52, 145, 89, 21, 135, 102, 112, 67, 8,
    2, 85, 150, 23, 56, 137, 100, 65, 112, 35,
    80, 40, 3, 133, 25, 114, 65, 151, 54, 100,

    146, 3, 39, 69, 84, 105, 24, 113, 134, 48,
    97, 57, 83, 7, 146, 40, 70, 16, 132, 117,
    18, 36, 73, 7, 115, 128, 101, 88, 145, 54,

    3, 129, 18, 117, 54, 73, 84, 151, 40, 96,
    100, 72, 114, 134, 32, 53, 25, 81, 147, 7,
    6, 18, 136, 119, 57, 83, 97, 68, 32, 149
};

//NOTE(erick): TURNING OFF THE DISPLAY AT NIGHT
#define HOUR_TO_TURN_OFF 00
#define HOUR_TO_TURN_ON  06

// NOTE(erick): We set the `new_animation_step_flag` every time we start and stop an animation
// so the display changes imediately.
void start_animation() {
    is_animating = 1;
    animation_counter = 0;
    animation_milliseconds = 0;
    new_animation_step_flag = 1;
}

void stop_animation() {
    is_animating = 0;
    new_animation_step_flag = 1;
}

uint8 is_in_display_off_range() {
    return clock_current_hour >= HOUR_TO_TURN_OFF &&
        clock_current_hour < HOUR_TO_TURN_ON;
}

void setup() {
    noInterrupts();

    // Configuring output pins
    DDRB = 0x27; // 00100111
    DDRC = 0x20; // 00100000 -- PORTC5 is unconnected and configured as output to avoid a floating state.

    DDRD = 0xff;

    // Internal pull-ups
    PORTB |= 0x18; // 00011000
    PORTC |= 0x1f; // 00011111

    turn_display_on();

    // Initialize rotary encoder

    // when not started in motion, the current state of the encoder should be ROTARY_ENCODER_LATCH_STATE
    __rotary_encoder_old_state = ROTARY_ENCODER_LATCH_STATE;

    // start with position 0;
    __rotary_encoder_internal_position = 0;
    rotary_encoder_position = 0;
    __rotary_encoder_old_internal_position = 0;

    // Interrupts for the rotary encoder
    PCICR |= (1 << PCIE0);
    PCMSK0 |= (1 << PCINT3) | (1 << PCINT4);

    // --- Timer 1 initialization ---
    TCCR1A = 0;
    TCCR1B = 0;
    TCNT1 = 0;

    OCR1A = 15998;
    TCCR1B |= (1 << WGM12);
    TCCR1B |= (1 << CS10);
    TIMSK1 |= (1 << OCIE1A);

    interrupts();

    update_display(change_all);

}

// --- Timer 1 interrupt routine ---
ISR(TIMER1_COMPA_vect) {
    milliseconds++;
    if(milliseconds >= 1000) {
        milliseconds -= 1000;
        seconds_flag = 1;
    }

    if(is_animating) {
        animation_milliseconds++;
        if(animation_milliseconds == MILLISECONDS_PER_ANIMATION_STEP) {
            animation_milliseconds = 0;
            animation_counter++;
            new_animation_step_flag = 1;
            if(animation_counter == ANIMATION_STEPS) {
                stop_animation();
            }

        }
    }

    read_inputs();
}

// --- Pin change interrupt routine used by the rotary encoder ---
ISR(PCINT0_vect) {
    static int rotary_encoder_current_position = 0;

    read_rotary_encoder();
    if (rotary_encoder_current_position != rotary_encoder_position) {
        int8 diff = (int8) (rotary_encoder_current_position - rotary_encoder_position);
        rotary_encoder_current_position = rotary_encoder_position;

        display_fade_timeout = INITIAL_DISPLAY_FADE_TIMEOUT;

        if(!clock_is_running) {
            adjust_time(diff);
        }
    }
}

inline void increment_days() {
    clock_current_day++;
    if(clock_current_day <= days_in_mounths[clock_current_month - 1]) {
        return;
    }

    if(clock_current_day == 29 && (clock_current_year & 0x03) == 0) { // If the year is divisible by 4 we have a leap year
        return;
    }

    clock_current_day = 1;
    clock_current_month++;
    if(clock_current_month < 13) {
        return;
    }

    clock_current_month = 1;
    clock_current_year++;
    if(clock_current_year < 100) {
        return;
    }

    clock_current_year = 0;
}

inline uint8 increment_seconds() {
    clock_current_second++;
    if(clock_current_second < 60) {
        return seconds_change;
    }

    clock_current_second = 0;
    clock_current_minute++;
    if(clock_current_minute < 60) {
        return seconds_change | minutes_change;
    }

    clock_current_minute = 0;
    clock_current_hour++;
    if(clock_current_hour < 24) {
        return seconds_change | minutes_change | hours_change;
    }

    clock_current_hour = 0;
    increment_days();
    return seconds_change | minutes_change | hours_change;
}

inline void adjust_time(int8 diff) {
    uint8 change;
    if(display_mode == DISPLAY_TIME) {
        switch (input_bitfield & ((1 << IN_HMS0) | (1 << IN_HMS1))) {
            case 0x01 : // seconds
                clock_current_second += diff;
                if(clock_current_second == 60) clock_current_second = 0;
                if(clock_current_second == -1) clock_current_second = 59;

                change = seconds_change;
                break;
            case 0x02 : // minutes
                clock_current_minute += diff;
                if(clock_current_minute == 60) clock_current_minute = 0;
                if(clock_current_minute == -1) clock_current_minute = 59;

                change = minutes_change;
                break;
            case 0x03 : // hours
                clock_current_hour += diff;
                if(clock_current_hour == 24) clock_current_hour = 0;
                if(clock_current_hour == -1) clock_current_hour = 23;

                change = hours_change;
                break;
        }
    } else { // DISPLAY_DATE
        switch (input_bitfield & ((1 << IN_HMS0) | (1 << IN_HMS1))) {
            case 0x01 : // years
                clock_current_year += diff;
                if(clock_current_year == 100) clock_current_year = 0;
                if(clock_current_year == -1)  clock_current_year = 99;

                change = years_change;
                break;
            case 0x02 : // months
                clock_current_month += diff;
                if(clock_current_month == 13) clock_current_month = 1;
                if(clock_current_month == 0)  clock_current_month = 12;

                change = months_change;
                break;
            case 0x03 : // days
                uint8 n_days = days_in_mounths[clock_current_month - 1];
                if(clock_current_month == 2 && (clock_current_year & 0x03) == 0) {
                    n_days = 29;
                }

                clock_current_day += diff;
                if(clock_current_day == n_days + 1) clock_current_day = 1;
                if(clock_current_day == 0) clock_current_day = n_days;

                change = days_change;
                break;
        }

        change |= verify_and_correct_date();
    }

    update_display(change);
}

inline void display(int8 value, uint8 latch_selector) {
    PORTD = value;
    nop();
    nop();

    PORTB |= 1 << latch_selector;
    nop();

    PORTB &= ~(1 << latch_selector);
}

inline void update_display(uint8 change) {
    // NOTE(erick): Display is not updated while animating.
    if(is_animating) {
        // NOTE(erick): Getting the corect number from the corect part of the table.
        display(pgm_read_byte_near(animation_table + (ANIMATION_STEPS * 0) + animation_counter), 0);
        display(pgm_read_byte_near(animation_table + (ANIMATION_STEPS * 1) + animation_counter), 1);
        display(pgm_read_byte_near(animation_table + (ANIMATION_STEPS * 2) + animation_counter), 2);

    } else if(display_mode == DISPLAY_TIME) {
        if(change & seconds_change) {
            display(pgm_read_byte_near(div10_quot_rem_table + clock_current_second), 0);
        }
        if(change & minutes_change) {
            display(pgm_read_byte_near(div10_quot_rem_table + clock_current_minute), 1);
        }
        if(change & hours_change) {
            display(pgm_read_byte_near(div10_quot_rem_table + clock_current_hour), 2);
        }

    } else { // DISPLAY_DATE
        if(change & seconds_change) {
            display(pgm_read_byte_near(div10_quot_rem_table + clock_current_year), 0);
        }
        if(change & minutes_change) {
            display(pgm_read_byte_near(div10_quot_rem_table + clock_current_month), 1);
        }
        if(change & hours_change) {
            display(pgm_read_byte_near(div10_quot_rem_table + clock_current_day), 2);
        }
    }
}

inline void read_inputs() {
    input_array[input_array_current_index] = PINC & 0x1f;
    input_array_current_index = (input_array_current_index + 1) & 0x0f; // increment modulo 16

    if(input_array_current_index == 0) {
        old_input_bitfield = input_bitfield;
        input_bitfield = input_array[N_INPUT_SAMPLES - 1]; // Last read sample

        // README: This loop would be very happy been unrolled
        uint8 tmp0;
        uint8 tmp1;

        tmp0 = input_array[0] & input_array[1];
        tmp1 = (~input_array[0]) & (~input_array[1]);
        for(uint8 input_index = 2; input_index < N_INPUT_SAMPLES; input_index++) {
            tmp0 &= input_array[input_index];
            tmp1 &= (~input_array[input_index]);
        }

        input_valid_bits = tmp0 | tmp1;
        new_input_flag = 1;
    }
}

void loop() {
    if(new_input_flag) {
        new_input_flag = 0;

        if(input_valid_bits & (1 << IN_DATE_TIME)) {
            // TODO: Document this. Seriously, stop being lazy!!!
            uint8 new_diplay_mode = input_bitfield & (1 << IN_DATE_TIME);
            uint8 should_update_display = new_diplay_mode ^ display_mode;

            display_mode = new_diplay_mode;
            if(should_update_display) {
                update_display(change_all);
            }
        }

        if(input_valid_bits & (1 << IN_ADJUST)) {
            clock_is_running = input_bitfield & (1 << IN_ADJUST);
            // NOTE(erick): If we are animating and change to adjust
            // mode the animation has to stop.
            if(!clock_is_running && is_animating) {
                stop_animation();
            }
        }

        // NOTE(erick): If some input has changed since last time
        // and this input is valid, set the display fade timeout.
        if((old_input_bitfield ^ input_bitfield) & input_valid_bits) {
            display_fade_timeout = INITIAL_DISPLAY_FADE_TIMEOUT;
        }
    }

    if(seconds_flag) {
        seconds_flag = 0;

        digitalWrite(13, digitalRead(13));

        if(clock_is_running) {
            uint8 change = increment_seconds();

            // NOTE(erick): If we are here the clock
            // is running (i.e. not adjusting) and we have an
            // exact minute. These are the conditions to start
            // an animation.
            if(clock_current_second == 0) {
                start_animation();

            } else if(change) {
                update_display(change);
            }

            if(display_fade_timeout &&
               (change & seconds_change)) {
                display_fade_timeout--;
            }
        }
    }

    uint8 should_display_be_on  = expected_display_state();
    uint8 should_display_be_off = !should_display_be_on;

    if(is_display_on() && should_display_be_off) {
        turn_display_off();
    }

    if(!is_display_on() && should_display_be_on) {
        turn_display_on();
    }


    if(new_animation_step_flag) {
        new_animation_step_flag = 0;
        update_display(change_all);
    }

}

uint8 expected_display_state() {
    if(display_fade_timeout) { return true; }

    // NOTE(erick): If !clock_is_running (a.k.a. adjust mode) the
    // display should always be on.
    if(!clock_is_running) { return true; }

    return !is_in_display_off_range();
}

uint8 verify_and_correct_date() {
    if(clock_current_day > days_in_mounths[clock_current_month - 1]) {
        if(clock_current_month == 2 && (clock_current_year & 0x03) == 0) {
            clock_current_day = 29;
        } else {
            clock_current_day = days_in_mounths[clock_current_month - 1];
        }

        return days_change;
    }

    return 0;
}

inline void read_rotary_encoder() {
    uint8 current_state = (PINB >> 3) & 3;

    if(__rotary_encoder_old_state != current_state) {
        uint8 state = (__rotary_encoder_old_state << 2 ) | current_state;

        switch(state) {
            case (0 << 2 | 1) :
                __rotary_encoder_internal_position += -1;
                break;
            case (0 << 2 | 2) :
                __rotary_encoder_internal_position += 1;
                break;
            case (1 << 2 | 0) :
                __rotary_encoder_internal_position += 1;
                break;
            case (1 << 2 | 3) :
                __rotary_encoder_internal_position += -1;
                break;
            case (2 << 2 | 0) :
                __rotary_encoder_internal_position += -1;
                break;
            case (2 << 2 | 3) :
                __rotary_encoder_internal_position += 1;
                break;
            case (3 << 2 | 1) :
                __rotary_encoder_internal_position += 1;
                break;
            case (3 << 2 | 2) :
                __rotary_encoder_internal_position += -1;
                break;
            default:
                break;
        }

        if(current_state == ROTARY_ENCODER_LATCH_STATE) {
            int diff = (__rotary_encoder_internal_position - __rotary_encoder_old_internal_position) >> 2;

            if(diff > 0) {
                rotary_encoder_position++;
            } else if(diff < 0) {
                rotary_encoder_position--;
            }

            __rotary_encoder_old_internal_position = __rotary_encoder_internal_position;
        }

        __rotary_encoder_old_state = current_state;
    }
}

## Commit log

2018-05-26 Added kicad boards files.
    [Clock.dsn, Clock.kicad_pcb, Clock.sch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]
2018-05-26 Power Supply info.
2018-05-26 Added README.
    [Clock.dsn, Clock.kicad_pcb, Clock.sch]
